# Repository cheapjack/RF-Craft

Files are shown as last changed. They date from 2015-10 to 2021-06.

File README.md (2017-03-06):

# RF-Craft




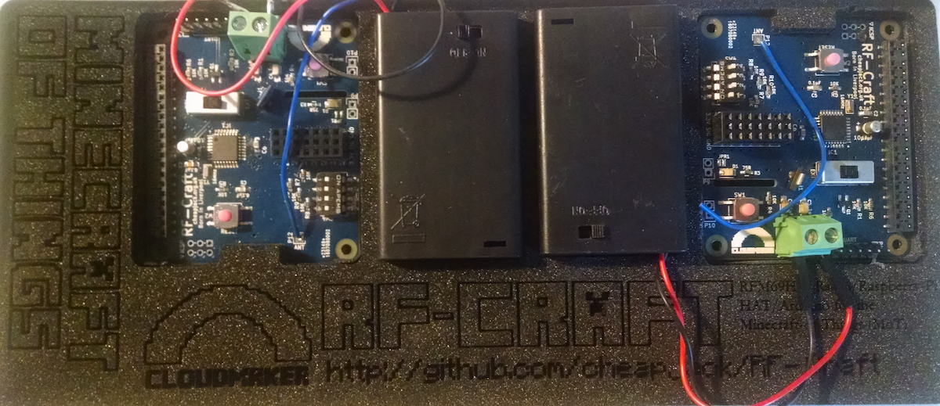
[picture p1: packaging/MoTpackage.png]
<br>
<br>

RF-Craft is a prototype Raspberry Pi [HAT](https://github.com/raspberrypi/hats) (**H**ardware **A**ttached on **T**op) arduino clone to send `mcpi` API commands wirelessly to a minecraft server. RF-Craft was built as part of Ross Dalziel's [OK Sparks Project](http://domesticscience.org.uk) and a spin-out from the [FACT](http://fact.co.uk/) [CloudMaker](http://www.fact.co.uk/projects/cloudmaker-making-minecraft-real.aspx) project research and inspired by resilient networks, the work of [Martin O'Hanlon](https://github.com/martinohanlon/mcpi) where `mcpi` is maintained via Mojang, [Shrimping.it](http://start.shrimping.it) and Minecraft modders worldwide. 

Full info from the [CloudMaker Repo](https://github.com/cheapjack/CloudMaker)

It is a board to help teach the **Internet of Things** and is inspired by the wider Minecraft community and culture where young people develop their own skillsets in order to take part in the games culture. In many ways it is the first game in mainstream consciousness where players take control of elements of the games infrastructure, independent of the original developer *Mojang*, often becoming their own **sysadmins** using custom servers for games they want to play and as a consequence, with considerable transferable skills in coding and IoT. 

Minecraft is not an open source project but the game community have, in a sense, opened up elements of it to allow extensive modding and creative hacking. This adhoc technical *culture* is what is the most valuable, not the game itself or even it's potential to educate, which is a consequence of this. After a good deal of research we've concluded that Minecraft is more representative of an independent learning culture and ecosystem on it's own and others borrowed terms and with it's own diversity. This is exciting but not necessarily always helpful to educators or learners.  

With experience, we think it should not really be confused with a universal *service* or *platform* that could be easily exploited for formal mainstream education.

Current owners, Microsoft are developing an education *platform* through [Minecraft Education](https://education.minecraft.net/). This is a very specific version of the game and so has very specific requirements to use. In this sense it *is* a platform, but like many platforms in the real world once you are on one its hard to jump to another without ladders, ropes or expensive jetpacks. We've all played on Parkour servers so we know how hard that can be!

We've tried to package up a range of resources, examples and hardware that could allow you to play with connecting versions of the game with the real world with sensors and buttons. 

Finding the right version of the game to experiment with is difficult and has it's own quite steep and confusing learning curve. We recommend keeping it simple and experimenting on a Pi. The Pi version is version 1.0 or something. It's simple and it's not changing. It's also free. There's an established community out there using the python [mcpi API](https://github.com/martinohanlon/mcpi) for it like [Martin O'Hanlon](https://github.com/martinohanlon/) and making cool stuff for it like [PatternCraft](http://patterncraft.co/).

So we've tried keeping it simple by making simple Raspeberry Pi HATS that can transmit and receive serial messages which you can parse into commands in the Raspberry Pi version of Minecraft you can make simpel HelloWorld Text Adventures, [Models of Railways](https://github.com/cheapjack/RF-Rail-Craft) or all the way up to interacting with [data](https://github.com/cheapjack/MoT), the [International Space Station](https://github.com/astro-pi/SpaceCRAFT) to punchard readers that make music just like PatternCraft.

This Open source Radio messaging system uses the [RFM69HW tranceiver chip](https://lowpowerlab.com/shop/rfm69hw)(based on the Lowpowerlab Moteino) and Frequency 868MHz to report to a central reciever to perform minecraft actions.

Its designed as a Minecraft-of-Things deluxe development board bridging the gap between Pi and Arduino without depending on both. One design parameter was to have good signal penetration through Victorian concrete and the concrete of many arts centres and/or schools for the [Ok Sparks!](http://slyrabbit.net/ok-sparks) project by [Domestic Science](http://domesticscience.org.uk). 

It was designed by artist [Ross Dalziel](http://cheapjack.org.uk) and open source engineer and technician in residence at [DoESLiverpool](http://doesliverpool.com) [Patrick Fenner AKA @DefProc](http://www.deferredprocrastination.co.uk/) and funded by [FACT](http://fact.co.uk/) and  [IT as a Utility (ITaaU) Network](http://www.itutility.ac.uk) for the [CloudMaker](http://www.fact.co.uk/projects/cloudmaker-making-minecraft-real.aspx) project following 2 years of research into the game as a social learning tool which we've since realised is, as we've said, more like a *culture*

### Features

 * On board button and LED, 
 * Digital input for a Dallas DS18B20 one-wire temperature sensor (with pullup resistor) and power rail 
 * 6 analog inputs broken out with power
 * Battery power breakout
 * Pi/External mode jumpers
 * IDE Free reciever/transmitter/Node programming switch
 * It can act as a powered HAT reciever/transmitter on board a Pi or as an independent battery powered arduino radio receiver or transmitter.
 * Open Source: Not cheap but open; but you can build them yourself!
 * Good singnal penetration through concrete castles
 * Need IoT Minecraft workshop & WiFi Down? Network Administrator at lunch? Got Pi, Got HAT Got RF-Craft - no problem!
 * Need radio arduinos for IoT prototype? Sick of Minecraft? Caps falling out of your shrimp? No problem use elsewhere!
 * Send Commands to a Receiver HAT and your Raspbians local Minecraft Pi Edition server
 * Send Commands to the Rasperry Juice Plugin on a CanaryMod server
 * Send Commands to the Rasperry Juice Plugin on `mc.fact.co.uk:25589`

### Message Format

messages are constructed of a `uint8_t` for node_id, followed by an `int8_t` for action

Possible action messages:

 * -1 : set_id
 *  0 : query_id
 *  1 : button press
 *  2 : error
 *  3 : OK

common key for messages: "changemechangeme"

all radios are in group: 87

Transmitter `node_ids` for buttons can be 1-100 but the onboard `node_id` switch can set them to 1-15 in Binary. By default with the big mode switch set to **EXT** the HAT is in transmitter mode and you need to set the `node_id` switch to 1-15. When the mode switch is set to **RPI** then the `node_id` is 254 which is a receiver. 

### Getting Started

The easiest thing to do is clone this repo into your `/home/pi` folder either with git or `wget https://github.com/cheapjack/RF-Craft/archive/master.zip` then `unzip`

You can install git with `sudo apt-get install git-core`
Then `git clone https://github.com/cheapjack/RF-Craft.git`

Then you can modify the `HelloPi.py` or `HelloSerial.py` `python 2.7` code and play with the transmitter and receiver boards pairs out of the box without even having to put the arduino sketches on. Unless you're making them yourselves from the details in the repo then well it's your box.

Then for full details you can read the nearby `GettingStarted.md` file

### RF-Craft

### Background

[The Minecraft Of Things](http://minecraftofthings.tumblr.com) sprang from research with [FACT](http://fact.co.uk/), [Dr Mark Wright](https://twitter.com/dr_mark_wright), [Adrian McEwen](http://www.mcqn.com/) and Paul Harter of [PrintCraft](http://www.printcraft.org/) funded by [IT as a Utility (ITaaU) Network](http://www.itutility.ac.uk) for the [CloudMaker](http://www.fact.co.uk/projects/cloudmaker-making-minecraft-real.aspx) project

Looking into how the Raspberry Pi could be used as an entry into embedded systems, physical computing and the Internet Of Things(IoT) we developed something that could be used in many contexts with simplicity at its core and with ideas that touched on data literacy, resilient networks and security. 

One of the big issues with use of Minecraft in education is networking often educators dont have the time or access to setup a school network for a wireless sensors to communicate with the game; we wanted to be able to be independent of this and for people to setup their own adhoc networks to follow how networks are used in real world applications.

For the final distribution of CloudMaker research we focussed on packaging up resources to help understand the Internet Of Things through Minecraft.

We took diverse approaches to reflect real IoT ecosystems; tried not to re-invent the wheel but point to fascinating education work going on in technology and post 'Maker' culture. 

We made simple arduino on a breadboard interfaces inspired by [Shrimping.It](http://start.shrimping.it) for interacting with minecraft over wired USB/FTDI adaptors, [ShrimpCraft](https://github.com/cheapjack/ShrimpCraft), a WiFi on a breadboard system [Cockle-Craft-of-Things](https://github.com/mcqn/cocklecraft-of-things) with MCQN Ltd. 

For RF-Craft we made a super robust custom PCB arduino RFM69 clone that has a more plug & python & play approach.

The receiver button pairs allow you to send wireless messages to a range of minecraft servers for augmented reality gaming and learning the Internet of Things (IoT) 

### Resources

This uses Martin O'Hanlon's [mcpi API](https://github.com/martinohanlon/mcpi) the Minecraft: Pi Edition API Python Library and his and Zhuowei's [Canary Raspberry Juice](https://github.com/martinohanlon/CanaryRaspberryJuice) plugin for use with FACT's CloudMaker Minecraft Server

### The FACT Server

The FACT CloudMaker Server is a server for prototyping multiplayer `mcpi` activity. Details for how to log on are at the [CloudMaker portal repo](https://github.com/cheapjack/CloudMaker/)

#### Plugins

 * Printbot
 * ScriptCraft
 * WorldEdit
 * Essentials

You can view the [Minecraft CloudMaker Server with this link](http://89.34.96.47:8125/)



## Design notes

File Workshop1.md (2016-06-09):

## Getting Started with RF-Craft

CloudMaker

Welcome to a teacher focussed workshop on using (and testing) RF-Craft!

### Simple setup and python Hello! sketch

We are going to cover 3 ways of using RF-Craft:

 * Sending messages to a built in Minecraft instance on board the Pi with a `receiver` HAT `Hello.py`
 * Sending messages to a local CanaryMod Server `HelloCanary.py`
 * Sending messages to the FACT Minecraft server at `mc.fact.co.uk:25565` `HelloCloudMaker.py`

They all use the same python code using the `mcpi` API 

Its well worth reading Martin O'Hanlon's [Stuff About Code API Reference](http://www.stuffaboutcode.com/p/minecraft-api-reference.html), his [Tutorial](http://www.stuffaboutcode.com/2013/04/minecraft-pi-edition-api-tutorial.html) and notes on [Connecting to other servers](http://www.stuffaboutcode.com/2014/10/minecraft-raspberryjuice-and-canarymod.html) that all the code side is based on.

### Out Of The Box

RF-Craft v1.1

Your receiver and transmitter already have receiver.ino and button.ino uploaded to them but if your in the first workshop you need to change the group ID in the Arduino code so messages from other people dont get confused with each other but we will cover that later.

Look at the 2 RF Craft boards in your pack; you will see some plastic jumpers next to the long ATMEGA328 chip: one will be connected to the `|--PI--|` side, and another connected to `|External|`. Pi is the `receiver` and External is the `button` and they have the associated code on there.

All you need to do is get the receiver HAT on your Pi header, ensure the jumpers are set to `|--PI--|`, start the PI up, get it into Desktop mode `startx`, start a minecraft game and then power up the battery pack on the button HAT, the one with jumpers set to `|External|`.

You then need to clone this repo into your home directory and use the `Hello*.py` python programmes to receive the button messages over serial and then send commands to the minecraft server of your choice.  

Do this by opening a terminal window on the Pi and going `$ cd ~` then `$ ls` to list your files
Then either use `git` or `wget https://github.com/cheapjack/RF-Craft/archive/master.zip` then `unzip master.zip`

You can install git with `sudo apt-get install git-core`
Then `git clone https://github.com/cheapjack/RF-Craft.git`

Then you can run python code like this from the terminal 

`$ python Hello.py`

To stop it press `ctrl` & `C`

Then you can edit it with a text editor or edit and run the code with the IDLE Python IDE on the Pi

We are going to run you through the basic useage today and will provide further reading to experiment with other servers

#### Hello World!

We are going to start with a HAT receiver on board the PI: You generally talk to the server with the API like this:

```
    from mcpi import minecraft
    mc = minecraft.Minecraft.create()

    mc.postToChat("Hello World!")
```

You can specify an exact server address and port in the `.create()` call like this

```
mc = minecraft.Minecraft.create("127.0.0.1")
# This is the server running on your computer, the localhost address
# or mc =minecraft.Minecraft.create("mc.fact.co.uk") 
# or mc = minecraft.Minecraft.create(server.address)
# In this case we refer to a file called server.py that specifies a server address
# Or you can just use:
# mc = minecraft.Minecraft.create()
# By default the server will be a local instance of the CanaryMod server

```

Next you need to `import serial` at the top of the programme so we can receive our HAT messages

```
#########################
# Pi/PC/Mac/Linux  mode #
# RF-Craft HAT receiver #
#########################
# use the default serial port, 'COM1', '/dev/ttyAMA0' this will change platform to platform '/dev/tty.usbserial-A400f5sm'
# You can list your serial ports in Terminal
# Open a terminal window from the menu bar
# $ ls /dev
# It should show something like this '/dev/ttyAMA0', 9600
# So therefore define your serial object like this
# Or use the serial id that shows up on the Arduino IDE
ser = serial.Serial('/dev/ttyAMA0', 9600)
#ser = serial.Serial('COM1', 9600)
#ser = serial.Serial('/dev/tty.usbserial-A400f5sm', 9600)
#ser = serial.Serial('/dev/tty.SLAB_USBtoUART', 9600)
#########################################################
# The Button sends the serial message (node , action)   #
# node is the value in #define NODEID in Line 10 of the #
# Arduino code                                          #
# in ~/RF-Craft/arduino/button/button.ino               #
# It comes with the default node of 1 on the arduino HAT#
#                                                       #
# action "1", "ButtonPressed"                           #
# action "2", "Error"                                   #
# action "3", "OK"                                      #
#                                                       #
#########################################################
```

Then we can setup our button receive message

`button1_received = "1,1\r\n"`

Finally we make a simple loop to respond to the button1_received value as serial receives it

```
while True:
    # This reads the ser object you defined before, the serial connected to the HAT
    serialcommand = str(ser.readline())
    if serialcommand == button5_received:
        print "Got mail from Button 5"
        mc.postToChat("Got mail from Button 5 saying " + serialcommand)
        mc.entity.setTilePos(4, 76,20, -64)
        sleep(1)
        mc.camera.setFollow()
```
### CanaryMod
We may not get to this in the workshop but another way of working is to run a server on a bigger computer and send messages to that.
Weve provided a server from the [CanaryMod Jenkins Repo](https://ci.visualillusionsent.net/) with a compatible plugin called Raspberry Juice and a CanaryMod server to send similar messages to a much more up to date world you can play with PC/Mac/Linux Minecraft running version `1.8`

You need to `$ cd ~/RF-Craft-master/CanaryForDistro/`
then `$ ls` to check whats there and `$ ./start.bat`
If you have JAVA installed all should be well, server will start and quit then edit the text file eula.txt  and change eula=false to eula=true and save the file. Then restart and you should be able to send messages to this server at the localhost address.

More details from Martin at his [Raspberry Juice Page](http://www.stuffaboutcode.com/2014/10/minecraft-raspberryjuice-and-canarymod.html)

CanaryMod and mcpi can't seem to agree on the coordinates of player positions and we've found you need to add -256 to x, add 64 to y and add -8 to z to make your coordinates match with the Minceraft client like this:

```
# translate mc coords on CanaryMod server for mcpi ones
# add this to x
mcx = -256
# - add this to y
mcy = 64
# - add this to z
mcz = -8
```

Likewise the FACT server can be equally confused and we ususally have to:

```
# translate mc coords on CloudMaker server for mcpi ones
# add this to x
mcx = 177
# - this from y
mcy = 64
# - this from z
mcz = 135
```

What you can also do is use your Pi as the bridge to sending messages to any minecraft server with the Raspberry Juice plugin installed like the FACT server at `mc.fact.co.uk`

You can play with all of the code in Martin O'Hanlon and David Whale's excellent book **Adventures in Minecraft** which you can get from [the Wiley publishers website](http://eu.wiley.com/WileyCDA/Section/id-823690.html) and experiment with things like [this](https://github.com/martinohanlon/minecraft-demos)

### Basic Tools

#### Multiple HATS & the Arduino IDE

If in the unlikey event you have a room full of receiver HATs then a button press message will be received by all receivers! To avoid this you can modify the arduino `button.ino` and `receiver.ino` NETWORKID value

Open the RF-Craft/arduino/button.ino sketch with your Arduino IDE

Download it [from here](https://www.arduino.cc/)

Connect the red FTDI cable adaptor to your button HAT and ensure that pins connect like this:
```
FTDI -> HAT
RST -> RST
RX -> RX
TX -> TX
VCC -> VIN
CTS -> NC #(NC stands for not Connected)
```

You can use any coloured combos of **female** to **female** jumper cable you like as long as they follow the wiring above

Now choose Tools/Board "Arduino/Genuino Uno" from the Arduino IDE menu
Choose Tools/Port "cu.usbserial-####" 
Choose Tools/Programmer "ArduinoISP"

Change line 9 from `#define NETWORKID   87` to a number of your choice:
`#define NETWORKID   88`

Now Upload your code to the HAT. As it's a button it's 3 jumpers are on the |External| side. Now you need to do the same process for your receiver HAT

Open RF-Craft/arduino/receiver/receiver.ino

Change line 9 from `#define NETWORKID   87` to a number of your choice, but the same number as your button ie::
`#define NETWORKID   88`

**REMEMBER** to move your receiver HAT jumpers to |--PI--| to |External| or the Arduino IDE cant see it. Then swap back over once you have uploaded successfully. 

#### Command Line

Behind every application on your computer is a command line where you can control it without the mouse.

 * `ls` - list where we are and what files we can look at 
 * `cd` - change directory go somewhere; we will stay here: ~/MoT/mcpi but if you get lost just type `cd ~/MoT-master`
 * `vim <file name.py>` - open a python file in vim 
 * `python HelloWorld.py` - runs the file HelloWorld.py to send a message to minecraft

#### Vim

[Vim](http://vim.rtorr.com/) (a version of Vi) is a text editor that lives pretty much on every server on the internet 

So you can edit things by typing `$ vi Hello.py` without needing the IDLE Python IDE editor.

Basically you move with the cursor keys and if you want to type something press `i` and you can type and delete as normal. When you're finished hit escape `esc` and if you want to `write` your changes type `:wq`  

 * `i` - insert text
 * `cursor keys` - move in the text
 * `esc` - stop inserting text
 * `:w` - write your changes
 * `:wq` - write your changes and quit vim

### Requirements

If you are running python code from a PC/Mac/Linux you will need to install `Python v2.7` from [here](https://www.python.org/about/gettingstarted/) and then you can follow the tutorials at [Raspberry Pi here](https://www.raspberrypi.org/learning/getting-started-with-minecraft-pi/worksheet/)

Id recommend looking at the [Hitchhiker's Guide To Python](http://docs.python-guide.org/en/latest/) for extensive tips on installing `Python 2.7` (much of what we use is transferable to `Python 3` but we stick with the Pi 2.7 for the time being) and although you can run from the command line you might want to use the Idle IDE. I'd also consider using Virtual Environments  [virtualenv](http://docs.python-guide.org/en/latest/dev/virtualenvs/).

Other useful stuff you can install are

`$ sudo apt-get install vim`
`$ sudo apt-get install screen`
`$ sudo apt-get install wicd-curse`s

### Shrimps

We've also used mcpi with the *brilliant* **Shrimped Arduino kits** from [Shrimping.it](http://shrimping.it/blog/) at its core and used prototype methods for visualising raw temperature and turbdiity data on onboard LED flashers, in Processing and in Minecraft. We used this method for the [ShrimpCraft](https://github.com/cheapjack/ShrimpCraft) project

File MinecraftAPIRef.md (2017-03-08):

# Minecraft API 

This is [Martin O'Hanlon's](https://github.com/martinohanlon) reference for the Minecraft Python API Library, which is supported on Minecraft: Pi edition and the PC/Mac/Linux version using the RaspberryJuice plugin.

If you want to know more about how to use the API, including tutorials, see his projects and download his code, visit my minecraft page.

Structure
 * minecraft.py
  * Class Minecraft - main class for connecting and interacting with the game
   * Class camera - changing camera angle and postion
   * Class player - getting and changing the players position and setting
   * Class entity - getting and changing entities position and setting
   * Class events - retreiving events which have occured in the game
 * block.py
  * Class Block - definition of a block, specifically its type
 * event.py
  *Class BlockEvent - definition of a block event, specifically what event, what block and what player
 * vec3.py
  * Class Vec3 - generic class for managing a 3 dimension vector (i.e. x,y,z)
 * connection.py - internal module used by the api
 * util.py - internal module used by the api

###Compatability
Not all functions and block types are available on all version of the api

PiEditionAvailable on Minecraft: Pi edition
Bukkit/CanaryModAvailable on RaspberryJuice

## Minecraft
"Main class for interacting with the Minecraft world, includes functions for creating a connection, modifying players and blocks and capturing events"

#### .create(address = "localhost", port = 4711)
"Create connection to Minecraft (address, port) => Minecraft object"
PiEdition
Bukkit/CanaryMod

```
#use default address and port
mc = minecraft.Minecraft.create()
#specify ip address and port
mc = minecraft.Minecraft.create("192.168.1.1", 4711)
```

#### .getBlock(x,y,z)
"Get block (x,y,z) => id:int"
PiEdition
Bukkit/CanaryMod

```
#retrieves the block type for the block at 0,0,0
blockType = mc.getBlock(0,0,0)
```

#### .getBlocks(x0,y0,z0,x1,y1,z1)
"Get a cuboid of blocks (x0,y0,z0,x1,y1,z1) => [id:int]"
Bukkit/CanaryMod

```
#get the block ids in a cuboid
blocks = mc.getBlocks(-1,-1,-1,1,1,1)
for block in blocks:
    print block
```

#### .getBlockWithData(x,y,z)
"Get block with data (x,y,z) => Block"
PiEdition
Bukkit/CanaryMod

```
#retrieves a block object for the block at 0,0,0
blockObj = mc.getBlockWithData(0,0,0)
```

#### .setBlock(x,y,z)
"Set block (x,y,z,id,[data])"
PiEdition
Bukkit/CanaryMod

```
#sets a block at an x, y, z co-ordinate to a particular type
mc.setBlock(0,0,0,block.DIRT.id)
#sets a block to a particular type and 'subtype'
mc.setblock(0,0,0,block.WOOD.id, 1)
```

#### .setBlocks(x0,y0,z0,x1,y1,z1,blockType, blockData)
"Set a cuboid of blocks (x0,y0,z0,x1,y1,z1,id,[data])"
PiEdition
Bukkit/CanaryMod

```
#sets many blocks at a time, filling the gap between 2 sets of x, y, z co-ordinates
mc.setBlocks(-1, -1, -1, 1, 1, 1, block.STONE.id)
```

#### .getHeight(x,z)
"Get the height of the world (x,z) => int"
PiEdition
Bukkit/CanaryMod

```
#find the y (vertical) of an x, z co-ordinate which represents the 'highest' (non-air) block
y = mc.getHeight(0,0)
```

#### .getPlayerEntityIds()
"Get the entity ids of the connected players => [id:int]"
PiEdition
Bukkit/CanaryMod

```
#get the entity ids of the players connected to the game
entityIds = mc.getPlayerEntityIds()
for entityId in entityIds:
    print entityId
```

#### .getPlayerEntityId(playerName)
"Get the entity id for a named player => [id:int]"
Bukkit/CanaryMod

```
#get the entity id of a name player 'martinohanlon'
entityId = mc.getPlayerEntityId("martinohanlon")
print entityId
```

#### .saveCheckpoint()
"Save a checkpoint that can be used for restoring the world"
PiEdition

```
mc.saveCheckpoint()
```

#### .restoreCheckpoint()
"Restore the world state to the checkpoint"
PiEdition

```
mc.restoreCheckpoint()
```

#### .postToChat(message)
"Post a message to the game chat"
PiEdition
Bukkit/CanaryMod

```
#write 'Hello Minecraft World' to the chat window
mc.postToChat("Hello Minecraft World")
```

#### .setting(setting, status)
"Set a world setting (setting, status). keys: world_immutable, nametags_visible"
PiEdition
Bukkit/CanaryMod

```
#change world immutable to True
mc.setting("world_immutable", True)
#change nametags_visible setting to False
mc.setting("nametags_visible", False)
```

### Minecraft.player
#### .getPos()
"Gets the player's position in the world as a Vec3 of floats (decimal numbers), if the player is in the middle of a block x.5 is returned"
PiEdition
Bukkit/CanaryMod

```
#get players position as floats
playerPos = mc.player.getPos()
```

#### .setPos(x,y,z)
"Moves the player to a position in the world by passing co-ordinates ([x,y,z])"
PiEdition
Bukkit/CanaryMod

```
#set the players position as floats
mc.player.setPos(0.0,0.0,0.0)
```

#### .getTilePos()
"Gets the position of the 'tile' the player is currently on."
PiEdition
Bukkit/CanaryMod

```
#get the position of the tile the players is on
playerTile = mc.player.getTilePos()
```

#### .setTilePos(x,y,z)
"Move the player to a tile position in the world by passing co-ordinates ([x,y,z])"

```
#set the position of the tile the player is on
mc.player.setTilePos(0,0,0)
```

#### .setting(setting, status)
"Set a player setting (setting, status). keys: autojump"

```
#change the autojump setting to True
mc.player.setting("autojump", True)
```

#### .getRotation()
"Get the rotational angle (0 to 360) for the player => [angle:float]"

```
#get the rotation of the player
angle = mc.player.getRotation()
print angle
```

#### .getPitch()
"Get the pitch angle (-90 to 90) for the player => [pitch:float]"

```
#get the pitch for the player
pitch = mc.player.getPitch()
print pitch
```

#### .getDirection()
"Get unit vector of x,y,z for the player's direction => [Vec3]"

```
#get the player's direction
direction = mc.player.getDirection()
print direction
```

### Minecraft.entity
The entity functions are used in conjunction with the .getPlayerEntityIds() function to interact with the entity (or players) in a game.  Entity functions are useful for multiplayer games.  

```
#get the entity ids of the players connected to the game
entityIds = mc.getPlayerEntityIds()
1stEntityId = entityIds[0]
2ndEntityId = entityIds[1]
```

#### .getPos(entityId)
"Gets an entities position in the world as a Vec3 of floats (decimal numbers), if the entity is in the middle of a block x.5 is returned"

```
#get first entity position as floats
entityPos = mc.entity.getPos(entityId)
```

#### .setPos(entityId,x,y,z)
"Moves the entity to a position in the world by passing co-ordinates ([x,y,z])"

```
#set the players position as floats
mc.player.setPos(entityId,0.0,0.0,0.0)
```

#### .getTilePos(entityId)
"Gets the position of the 'tile' the entity is currently on."

```
#get the position of the tile the entity is on
entityTile = mc.entity.getTilePos(entityId)
```

#### .setTilePos(entityId, x,y,z)
"Move the entity to a tile position in the world by passing co-ordinates ([x,y,z])"

```
#set the position of the tile the entity is on
mc.player.setTilePos(entityId,0,0,0)
```

#### .getRotation(entityId)
"Get the rotational angle (0 to 360) for an entity => [angle:float]"

```
#get the rotation of an entity
angle = mc.entity.getRotation(entityId)
print angle
```

#### .getPitch(entityId)
"Get the pitch angle (-90 to 90) for an entity => [pitch:float]"

```
#get the pitch for an entity
pitch = mc.entity.getPitch(entityId)
print pitch
```

#### .getDirection(entityId)
"Get unit vector of x,y,z for an entities direction => [Vec3]"

```
#get and entities direction
direction = mc.entity.getDirection(entityId)
print direction
```

### Minecraft.camera

#### .setNormal(entityId)
"Set camera mode to normal Minecraft view ([entityId])"

```
#set camera mode to normal for a specific player
mc.camera.setNormal(entityId)
```

#### .setFixed()
"Set camera mode to fixed view"

```
#set camera mode to fixed 
mc.camera.setFixed()
```

#### .setFollow(entityId)
"Set camera mode to follow an entity ([entityId])"

```
#set camera mode to follow for a specific player
mc.camera.setFollow(entityId)
```

#### .setPos(x,y,z)
"Set camera entity position (x,y,z)"

```
#set camera position to a specific position of x, y, z
mc.camera.setPos(0,0,0)
```

### Minecraft.events

#### .pollBlockHits()
"Block Hits (Only triggered by sword) => [BlockEvent]"

```
#get block event hits that have occured since the last time the function was run
blockEvents = mc.events.pollBlockHits()
for blockEvent in blockEvents:
    print blockEvent
```

#### .clearAll()
"Clear all old events"

```
#clear all events that have happened since the events where last got
mc.events.clearAll()
```

### Block
"The definition of a Block in Minecraft, used to describe a block type and (if applicable) its data; also contains constants for the blocks type id's, e.g. BLOCK.AIR.id"

```
#create block of a specific type
blockObj = block.Block(id)
#create a block of a specific type and apply a data value
blockObj = block.Block(id, data)
```

#### .id

"The id (or type) of block"

```
AIR                 = Block(0)
STONE               = Block(1)
GRASS               = Block(2)
DIRT                = Block(3)
COBBLESTONE         = Block(4)
WOOD_PLANKS         = Block(5)
SAPLING             = Block(6)
BEDROCK             = Block(7)
WATER_FLOWING       = Block(8)
WATER               = WATER_FLOWING
WATER_STATIONARY    = Block(9)
LAVA_FLOWING        = Block(10)
LAVA                = LAVA_FLOWING
LAVA_STATIONARY     = Block(11)
SAND                = Block(12)
GRAVEL              = Block(13)
GOLD_ORE            = Block(14)
IRON_ORE            = Block(15)
COAL_ORE            = Block(16)
WOOD                = Block(17)
LEAVES              = Block(18)
GLASS               = Block(20)
LAPIS_LAZULI_ORE    = Block(21)
LAPIS_LAZULI_BLOCK  = Block(22)
SANDSTONE           = Block(24)
BED                 = Block(26)
COBWEB              = Block(30)
GRASS_TALL          = Block(31)
WOOL                = Block(35)
FLOWER_YELLOW       = Block(37)
FLOWER_CYAN         = Block(38)
MUSHROOM_BROWN      = Block(39)
MUSHROOM_RED        = Block(40)
GOLD_BLOCK          = Block(41)
IRON_BLOCK          = Block(42)
STONE_SLAB_DOUBLE   = Block(43)
STONE_SLAB          = Block(44)
BRICK_BLOCK         = Block(45)
TNT                 = Block(46)
BOOKSHELF           = Block(47)
MOSS_STONE          = Block(48)
OBSIDIAN            = Block(49)
TORCH               = Block(50)
FIRE                = Block(51)
STAIRS_WOOD         = Block(53)
CHEST               = Block(54)
DIAMOND_ORE         = Block(56)
DIAMOND_BLOCK       = Block(57)
CRAFTING_TABLE      = Block(58)
FARMLAND            = Block(60)
FURNACE_INACTIVE    = Block(61)
FURNACE_ACTIVE      = Block(62)
DOOR_WOOD           = Block(64)
LADDER              = Block(65)
STAIRS_COBBLESTONE  = Block(67)
DOOR_IRON           = Block(71)
REDSTONE_ORE        = Block(73)
SNOW                = Block(78)
ICE                 = Block(79)
SNOW_BLOCK          = Block(80)
CACTUS              = Block(81)
CLAY                = Block(82)
SUGAR_CANE          = Block(83)
FENCE               = Block(85)
GLOWSTONE_BLOCK     = Block(89)
BEDROCK_INVISIBLE   = Block(95)
STONE_BRICK         = Block(98)
GLASS_PANE          = Block(102)
MELON               = Block(103)
FENCE_GATE          = Block(107)
GLOWING_OBSIDIAN    = Block(246)
NETHER_REACTOR_CORE = Block(247)
```

#### .data
"The data (or sub-type) of a block"

Data Values of blocks:
```
WOOL:
0: White
1: Orange
2: Magenta
3: Light Blue
4: Yellow
5: Lime
6: Pink
7: Grey
8: Light grey
9: Cyan
10: Purple
11: Blue
12: Brown
13: Green
14: Red
15:Black

WOOD:
0: Oak (up/down)
1: Spruce (up/down)
2: Birch (up/down)
(below not on Pi)
3: Jungle (up/down)
4: Oak (east/west)
5: Spruce (east/west)
6: Birch (east/west)
7: Jungle (east/west)
8: Oak (north/south)
9: Spruce (north/south)
10: Birch (north/south)
11: Jungle (north/south)
12: Oak (only bark)
13: Spruce (only bark)
14: Birch (only bark)
15: Jungle (only bark)

WOOD_PLANKS (Not on Pi):
0: Oak
1: Spruce
2: Birch
3: Jungle

SAPLING:
0: Oak
1: Spruce
2: Birch
3: Jungle (Not on Pi)

GRASS_TALL:
0: Shrub
1: Grass
2: Fern
3: Grass (color affected by biome) (Not on Pi)

TORCH:
1: Pointing east
2: Pointing west
3: Pointing south
4: Pointing north
5: Facing up

STONE_BRICK:
0: Stone brick
1: Mossy stone brick
2: Cracked stone brick
3: Chiseled stone brick

STONE_SLAB / STONE_SLAB_DOUBLE:
0: Stone
1: Sandstone
2: Wooden
3: Cobblestone
4: Brick
5: Stone Brick
Below - not on Pi
6: Nether Brick
7: Quartz

Not on Pi
SNOW_BLOCK:
0-7: Height of snow, 0 being the lowest, 7 being the highest.

TNT:
0: Inactive
1: Ready to explode

LEAVES:
1: Oak leaves
2: Spruce leaves
3: Birch leaves

SANDSTONE:
0: Sandstone
1: Chiseled sandstone
2: Smooth sandstone

STAIRS_[COBBLESTONE, WOOD]:
0: Ascending east
1: Ascending west
2: Ascending south
3: Ascending north
4: Ascending east (upside down)
5: Ascending west (upside down)
6: Ascending south (upside down)
7: Ascending north (upside down)

LADDERS, CHESTS, FURNACES, FENCE_GATE:
2: Facing north
3: Facing south
4: Facing west
5: Facing east

[WATER, LAVA]_STATIONARY:
0-7: Level of the water, 0 being the highest, 7 the lowest

NETHER_REACTOR_CORE:
0: Unused
1: Active
2: Stopped / used up
```

### BlockEvent
"The definition of a BlockEvent in Minecraft, used to describe an event in Minecraft affecting blocks; returned by the Minecraft.events.pollBlockHits() method."
```
blockEvent = mc.events.pollBlockHits()
```
#### .type
"Type of block event; there is only 1 event currently implemented BlockEvent.HIT"

blockEventType = blockEvent.type

BlockEvent types:
0: BlockEvent.HIT

#### .pos
"The position of the block where the event occured, i.e. the block which was hit.  .pos returns a Vec3 object of x,y,z co-ordinates"

blockEventPos = BlockEvent.pos

#### .face
"The face of the block where the event occured"

blockEventFace = BlockEvent.face

#### .entityId
"entityId of the player who caused the block event, i.e. the player who hit the block"

blockEventPlayer - BlockEvent.entityId
Vec3
"The definition of a 3 part vector in Minecraft, i.e. a set of x, y, z co-ordinates; x and z are the horizontal positions, y the vertical"

#### position = vec3.Vec(0,0,0)

.x
"x position"

xPos = position.x
.y
"y position"

yPos = position.y
.z
"z position"

zPos = position.z

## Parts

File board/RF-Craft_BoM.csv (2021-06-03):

Qty | Line Item | Manufacturer | MPN | Octopart URL | Schematic Reference | Internal Part Number | Description | Total Qty (@ Batch Size: 1) | SKU | SKU | Packaging | Packaging | Unit Price (@ Batch Size: 1) | Unit Price (@ Batch Size: 1) | In Stock | In Stock | MOQ | MOQ | URL | URL | Distributor [null] | SKU [null] | Packaging [null] | Unit Price (@ Batch Size: 1) [null] | Line Total [null] | Batch Total [null] | In Stock [null] | MOQ [null] | URL [null] | Notes
 |  |  |  |  |  |  |  |  | Farnell | RS Components | Farnell | RS Components | Farnell | RS Components | Farnell | RS Components | Farnell | RS Components | Farnell | RS Components
1 | UWX1C100MCL1GB | Nichicon | UWX1C100MCL1GB | https://octopart.com/uwx1c100mcl1gb-nichicon-203107 | C1 |  | 10µF electrolytic capacitor | 1 | 8823022RL | 7395548 | Cut Tape |  |  |  | 2771 | 5845 | 5 | 10 | https://octopart-clicks.com/click/track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 | https://octopart-clicks.com/click/track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 | MCM Electronics | 31-8210 |  | 0.06591190000000001 | 0.06591190000000001 | 0.06591190000000001 | 39 |  | https://octopart-clicks.com/click/track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
3 | MC0805B104K500CT | Multicomp | MC0805B104K500CT | https://octopart.com/mc0805b104k500ct-multicomp-10529614 | C2, C5, C6 |  | 0.1µF 0805 Capacitor | 3 | 1759265RL |  | Cut Tape |  |  |  | 217450 |  | 10 |  | https://octopart-clicks.com/click/track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 |  | Newark | 06R3742 | Cut Tape | 0.067889257 | 0.203667771 | 0.203667771 | 11315 | 1 | https://octopart-clicks.com/click/track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
2 | MC1206B105K500CT | Multicomp | MC1206B105K500CT | https://octopart.com/mc1206b105k500ct-multicomp-10529438 | C3, C4 |  | 1µF 1206 Capacitor | 2 | 1759454RL |  | Cut Tape |  |  |  | 37488 |  | 5 |  | https://octopart-clicks.com/click/track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 |  | Newark | 06R4217 | Cut Tape | 0.252442577 | 0.504885154 | 0.504885154 | 3346 | 1 | https://octopart-clicks.com/click/track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
2 | MC0603N220K500CT | Multicomp | MC0603N220K500CT | https://octopart.com/mc0603n220k500ct-multicomp-10530022 | C7, C8 |  | 22pF 0603 Capacitor | 2 | 2309012RL |  | Cut Tape |  | 0.0046 |  | 30154 |  | 1 |  | https://octopart-clicks.com/click/track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 |  | element14 APAC | 2309012 | Cut Tape | 0.002774385136358088 | 0.005548770272716176 | 0.005548770272716176 | 74311 | 1 | https://octopart-clicks.com/click/track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
1 | SML-LX1206SRW-TR | Lumex | SML-LX1206SRW-TR | https://octopart.com/sml-lx1206srw-tr-lumex-550942 | D1 |  | Red 1206 LED | 1 | 2062242 |  |  |  | 0.0614 |  | 3173 |  | 1 |  | https://octopart-clicks.com/click/track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 |  | Farnell | 2062242 |  | 0.0614 | 0.0614 | 0.0614 | 3173 | 1 | https://octopart-clicks.com/click/track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
1 | TC1108-3.3VDBTR | Microchip | TC1108-3.3VDBTR | https://octopart.com/tc1108-3.3vdbtr-microchip-540426 | I1 |  | 3.3V low dropout, linear regulator | 1 | 1557422RL | 8234309 | Cut Tape |  | 0.388 |  | 1105 | 2600 | 1 | 20 | https://octopart-clicks.com/click/track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 | https://octopart-clicks.com/click/track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 | Avnet Express | TC1108-3.3VDBTR/BKN |  | 0.2418307611 | 0.2418307611 | 0.2418307611 | 43 | 1 | https://octopart-clicks.com/click/track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
1 | ATMEGA328P-PU | Atmel | ATMEGA328P-PU | https://octopart.com/atmega328p-pu-atmel-42866773 | IC1 |  | Push fit into socket | 1 | 1715487 | 6962260 |  |  | 2.35 | 2.39 | 8801 | 4969 | 1 | 1 | https://octopart-clicks.com/click/track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 | https://octopart-clicks.com/click/track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 | Seeed Studio | 310010051 |  | 1.977357 | 1.977357 | 1.977357 | 30000 | 1 | https://octopart-clicks.com/click/track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
1 | 1-2199298-9 | TE Connectivity | 1-2199298-9 | https://octopart.com/1-2199298-9-te+connectivity-39188588 | IC1 |  | DIP-28 Socket (solder to board) | 1 | 2445626 |  |  |  |  |  | 1234 |  | 10 |  | https://octopart-clicks.com/click/track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 |  | Onlinecomponents.com | 121992989 | Bulk | 0.268261433 | 0.268261433 | 0.268261433 | 1861 | 1 | https://octopart-clicks.com/click/track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
1 | RFM69HW-868S2 | RF Solutions | RFM69HW-868S2 | https://octopart.com/rfm69hw-868s2-rf+solutions-52732388 | IC2 |  | 868MHz High output, packet radio module | 1 |  |  |  |  |  |  |  |  |  |  |  |  | Digi-Key | RFM69HW-868S2-ND | Bag | 6.81529046 | 6.81529046 | 6.81529046 | 8 | 1 | https://octopart-clicks.com/click/track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
4 | REF-182665-03 |  |  |  | J1 |  | 40-pin surface mount, through hole header socket | 4
1 | M20-9992046 | Harwin | M20-9992046 | https://octopart.com/m20-9992046-harwin-2627752 | P1, P3, P4 |  | 1 part split over 3 positions | 1 | 1022262 | 6813007 |  |  |  |  | 1916 | 110 | 10 | 10 | https://octopart-clicks.com/click/track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 | https://octopart-clicks.com/click/track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 | Mouser | M20-9992046 |  | 0.40206259 | 0.40206259 | 0.40206259 | 889 |  | https://octopart-clicks.com/click/track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
1 | BSS138 | Fairchild Semiconductor | BSS138 | https://octopart.com/bss138-fairchild+semiconductor-13127972 | Q1 |  | N-channel MOSFET | 1 | 9845330 | 6710324 |  |  |  |  | 121317 | 13860 | 5 | 10 | https://octopart-clicks.com/click/track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 | https://octopart-clicks.com/click/track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 | Freelance Electronics | BSS138 |  | 0.00659119 | 0.00659119 | 0.00659119 | 11239 |  | https://octopart-clicks.com/click/track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
4 | MCWR08X1002FTL | Multicomp | MCWR08X1002FTL | https://octopart.com/mcwr08x1002ftl-multicomp-50550529 | R1, R2, R4, R5 |  | 10Kohm 0805 resistor | 4 | 2447553 |  | Cut Tape |  |  |  | 104420 |  | 10 |  | https://octopart-clicks.com/click/track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 |  | Farnell | 2447553 | Cut Tape |  |  |  | 104420 | 10 | https://octopart-clicks.com/click/track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
1 | CRGH0603J75R | TE Connectivity | CRGH0603J75R | https://octopart.com/crgh0603j75r-te+connectivity-24382109 | R3 |  | 75ohm 0603 resistor | 1 | 2331711 | 8075605 | Cut Tape |  |  | 0.47 | 3700 | 94 | 10 | 1 | https://octopart-clicks.com/click/track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 | https://octopart-clicks.com/click/track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 | RS Components | 8075605 |  | 0.47 | 0.47 | 0.47 | 94 | 1 | https://octopart-clicks.com/click/track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
1 | KSEK43GLFS | C&K Components | KSEK43G LFS | https://octopart.com/ksek43g+lfs-c%26k+components-33963906 | SW1 |  | Tactile pushbutton switch | 1 | 2435308 |  |  |  | 0.12 |  | 731 |  | 1 |  | https://octopart-clicks.com/click/track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 |  | Farnell | 2435308 |  | 0.12 | 0.12 | 0.12 | 731 | 1 | https://octopart-clicks.com/click/track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
1 | MCRSD16000F183000RR | Multicomp | MCRSD16000F183000RR | https://octopart.com/mcrsd16000f183000rr-multicomp-10528717 | Y1 |  | 16MHz crystal resonator | 1 | 2395958 |  |  |  | 0.169 |  | 4300 |  | 1 |  | https://octopart-clicks.com/click/track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 |  | element14 APAC | 2395958 |  | 0.1484296047951577 | 0.1484296047951577 | 0.1484296047951577 | 8591 | 1 | https://octopart-clicks.com/click/track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

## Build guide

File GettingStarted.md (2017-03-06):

## Getting Started with RF-Craft
#### AA Battery Pack - RF-Craft Button - Pi & Hat/Computer & UART - Serial - Command Line - Minecraft -  Simples!



**RF-Craft** is a *simple* messaging system to send serial messages by low power radio to a Raspberry Pi when attached as a HAT or any serial connection that uses a UART adaptor. Refer to Setup-RPi-Hat.md for setup instructions.

It comes in a receiver and transmitter pair. RF-Craft is essentially an experiment in designing physical IoT devices with young people to communicate with  Minecraft. Most of the learning here is about participatory ecosystems in the design process both for users and developers. 

But we wanted RF-Craft to let you do anything with these messages. So no Apps, complicated bluetooth pairing or custom software just open-source simplicity and `serial` communication the most basic and so univerally useful communication protocol. In our case we are using python-serial to parse `serial` messages into commands to `mcpi` a python API for the Raspberry Pi version of Minecraft because there is currently a community of young people and educators doing that. But equally they could move a robot, make a cup of tea or send a tweet

### Hardware

#### Out Of The Box

 * Your **receiver** is the **RF-Craft HAT** without battery flashed with the sketch `receiver.ino` 
 * Your **transmitter** is the **RF-Craft HAT** with a battery pack flashed with the sketch `button.ino` 

If you are within range of other transmitters you may want to change the `NETWORK_ID` and the `ENCRYPTKEY` in the Arduino code on both so messages from other people dont get confused with each other but we will cover that later. You will need a UART interface attached to the P1 UART jumpers next to the external power input [available here](http://start.shrimping.it/kit/cp2102.html)

You can still switch each HAT between transmitter & receiver mode when you are ignoring RaspberryPi and you want to use as an arduino radio. 

Look at the 2 RF Craft boards in your pack; you will see a sliding switch next to the tiny square ##ATMEGA328P## chip: set it to the **RPI** side and the board is a **receiver** ready to send the received serial commands through the HAT pins to a Raspberry Pi or over a UART interface (not included but [available here](http://start.shrimping.it/kit/cp2102.html)

**EXT** Pi is the **button** mode and lets you set an ID number with the set of 4 switches marked ON APEMS 1234. Set these switches off and on in binary to get `NODE_ID` numbers 1-15. 

 * So to get `NODE_ID 1` set switch 1 to *on* and 2-4 to *off* 
 * So to get `NODE_ID 2` set switch 2 to *on* and 1,3 & 4 to *off* 
 * To get `NODE_ID 3` set switch 1 & 2 to *on* and 3 & 4 to *off* and so on. 

Now you can use the button to send a message to your receiver.

## Software

### Simple setup and python Hello! sketches

RF-Craft works can work in a few ways 

 * Sending messages to a running Minecraft instance on board the Pi with a `receiver` HAT `Hello.py`
 * Sending messages to a local CanaryMod Server `HelloCanary.py`
 * Sending messages to the FACT Minecraft server at `mc.fact.co.uk:25589` `HelloCloudMaker.py`
 * Sending messages to each other, arduino to arduino and interacting with Serial on another computer using a UART serial adaptor for arduino
 * Sending & receiving serial messages with python to trigger text and other things. Check out Adventures-in-RFCraft.md

All minecraft options use the same python code using the `mcpi` API but we advise you stick with your Pi. Put it on the same wifi network and other RPi players could join and watch whats going on like we did for [RF-Rail-Craft](http://github.com/cheapjack/RF-Rail-Craft) for **Museum of Science & Industry Manchester** for the **Lever Prize** which [Cloudmaker](https://github.com/cheapjack/CloudMaker/) won kickstarting the **FACTLab** project Dr Mark Wright put together.

Its well worth reading Martin O'Hanlon's [Stuff About Code API Reference](http://www.stuffaboutcode.com/p/minecraft-api-reference.html), his [Tutorial](http://www.stuffaboutcode.com/2013/04/minecraft-pi-edition-api-tutorial.html). His work is the original inspiration for this project.

And if you want to interact with non-Pi servers read his notes on [Connecting to other servers](http://www.stuffaboutcode.com/2014/10/minecraft-raspberryjuice-and-canarymod.html) that all the code side is based on.

First get on the internet & clone this repo into your home directory and use the `Hello*.py` python programmes to receive the button messages over serial and then send commands to the minecraft server of your choice.  

Do this by opening a terminal window on the Pi and going `$ cd ~` then `$ ls` to list your files
Then either use `git` or `wget https://github.com/cheapjack/RF-Craft/archive/master.zip` then `unzip master.zip`

You can install git with `sudo apt-get install git-core`
Then `git clone https://github.com/cheapjack/RF-Craft.git` what's good about this is that you can get any future updates from this server with a simple `git pull`. Go [here for a git 101](https://rogerdudler.github.io/git-guide/) it's a useful thing to know and it really sets you up for open sourcing your work in the future. You can read about what Im interested in about git [here](https://gitlab.com/redock/critical-kits/blob/master/Why_Git.md)

Then you can run python code like this from the terminal 

`pi$ python HelloSerial.py`

To stop it press `ctrl` & `C`

Then you can edit it with a text editor like [vim](http://vim.rtorr.com/) Install **vim** with `pi$ sudo apt-get install vim` or edit and run the code with the built-in RPi IDLE Python IDE on the Pi.

### Testing

Before thinking about Minecraft lets check we are receiving serial.

Check you've got serial installed:
`sudo apt-get install python-serial`

Verify it all works by using screen
Install it first if you dont have it; its handy!
`sudo apt-get install screen`

then with your HAT connected in RPI mode or UART connected no another device listen on the `/dev/ttyS0` serial port at 9600 baudrate that your HAT communicates with. This port varies system to system.

`screen /dev/ttyS0 9600`

Power your other **RF-Craft HAT** in **EXT** mode and set a **NODE** value of 1 using the 1234 switch (next to the analoginput block on the board), and you should receive the message `1,1` which means `NODEID=1,Button Pressed`

**TIP** To set a node ID of 1 Just set the node switch 1 to ON which is 1 in binary
or for a node ID of 3 set the node switch 1 and 2 to ON, 3 in binary.

Now try `HelloSerial.py` on your Pi with `python HelloSerial.py`

#### Hello World!

Follow the guide at [Setup-RPi-Hat.md](Setup-RPi-Hat.md) in the Repo and run HelloSerial.py

`pi$ python HelloSerial.py` press your powered transmitter onboard button, watch the led flash morse code and you should receive the message "Got mail from Button 1"

#### Hello Minecraft World!

We are going to start with a HAT receiver on board the PI: You generally talk to the server with the API like this:

```
    from mcpi import minecraft
    mc = minecraft.Minecraft.create()

    mc.postToChat("Hello World!")
```

You can specify an exact server address and port in the `.create()` call like this

```
mc = minecraft.Minecraft.create("127.0.0.1")
# This is the server running on your computer, the localhost address
# or mc =minecraft.Minecraft.create("mc.fact.co.uk") 
# In this case we refer to a file called server.py that specifies a server address
# Or you can just use:
# mc = minecraft.Minecraft.create()

```
Remember to have Minecraft running on the Pi before running HelloPi.py
Next you need to `import serial` at the top of the programme so we can receive our HAT messages

```
#########################
# Pi/PC/Mac/Linux  mode #
# RF-Craft HAT receiver #
#########################
# use the default serial port, 'COM1', '/dev/ttyAMA0' this will change platform to platform '/dev/tty.usbserial-A400f5sm'
# Please refer to Setup-RPi-Hat.md for help setting up serial ports on the pi.
# On windows the ports are usually COM1, COM2 etc but you will need to look into that. We are focussing on the Pi
# On UNIX sysems/Pi or Linux you can list your serial ports in Terminal
# Open a terminal window from the menu bar
# $ ls /dev/tty*
# It should show up a list with one port something like this '/dev/ttyAMA0', 9600
# So therefore define your serial object like this
ser = serial.Serial('/dev/ttyS0', 9600)
#ser = serial.Serial('/dev/ttyAMA0', 9600)
#ser = serial.Serial('COM1', 9600)
#ser = serial.Serial('/dev/tty.usbserial-A400f5sm', 9600)
#ser = serial.Serial('/dev/tty.SLAB_USBtoUART', 9600)
#########################################################
# The Button sends the serial message (node , action)   #
# node is the value in #define NODEID in Line 10 of the #
# Arduino code which you can change with the 1-4 NODE_ID#
# switches                                              #
# in ~/RF-Craft/arduino/button/button.ino               #
# It comes with the default node of 1 on the arduino HAT#
#                                                       #
# action "1", "ButtonPressed"                           #
# action "2", "Error"                                   #
# action "3", "OK"                                      #
#                                                       #
#########################################################
```

Then we can setup our button receive variable to listen for a button press

`button1_received = "1,1\r\n"`

Finally we make a simple loop to respond to the button1_received value as serial receives it

```
while True:
    # This reads the ser object you defined before, the serial connected to the HAT
    serialcommand = str(ser.readline())
    if serialcommand == button1_received:
        print "Got mail from Button 1"
        mc.postToChat("Got mail from Button 1 saying " + serialcommand)
        mc.entity.setTilePos(4, 76,20, -64)
        sleep(1)
        mc.camera.setFollow()
```

### CanaryMod
We may not get to this in the workshop but another way of working is to run a server on a bigger computer and send messages to that.
Weve provided a server from the [CanaryMod Jenkins Repo](https://ci.visualillusionsent.net/) with a compatible plugin called Raspberry Juice and a CanaryMod server to send similar messages to a much more up to date world you can play with PC/Mac/Linux Minecraft running version `1.8`

You need to `$ cd ~/RF-Craft-master/CanaryForDistro/`
then `$ ls` to check whats there and `$ ./start.bat`
If you have JAVA installed all should be well, server will start and quit then edit the text file eula.txt  and change eula=false to eula=true and save the file. Then restart and you should be able to send messages to this server at the localhost address.

More details from Martin at his [Raspberry Juice Page](http://www.stuffaboutcode.com/2014/10/minecraft-raspberryjuice-and-canarymod.html)

CanaryMod and mcpi can't seem to agree on the coordinates of player positions and we've found you need to add -256 to x, add 64 to y and add -8 to z to make your coordinates match with the Minceraft client like this:

```
# translate mc coords on CanaryMod server for mcpi ones
# add this to x
mcx = -256
# - add this to y
mcy = 64
# - add this to z
mcz = -8
```

Likewise the FACT server can be equally confused and we ususally have to:

```
# translate mc coords on CloudMaker server for mcpi ones
# add this to x
mcx = 177
# - this from y
mcy = 64
# - this from z
mcz = 135
```

What you can also do is use your Pi as the bridge to sending messages to any minecraft server with the Raspberry Juice plugin installed like the FACT server at `mc.fact.co.uk`

You can play with all of the code in Martin O'Hanlon and David Whale's excellent book **Adventures in Minecraft** which you can get from [the Wiley publishers website](http://eu.wiley.com/WileyCDA/Section/id-823690.html) and experiment with things like [this](https://github.com/martinohanlon/minecraft-demos)

### Basic Tools

#### Multiple HATS & the Arduino IDE

If in the unlikey event you have a room full of receiver HATs then a button press message will be received by all receivers! To avoid this you can modify the arduino `button.ino` and `receiver.ino` NETWORKID value

Open the RF-Craft/arduino/button.ino sketch with your Arduino IDE

Download it [from here](https://www.arduino.cc/)

Connect the red FTDI cable adaptor to your button HAT and ensure that pins connect like this:
```
FTDI -> HAT
RST -> RST
RX -> RX
TX -> TX
VCC -> VIN
CTS -> NC #(NC stands for not Connected)
```

You can use any coloured combos of **female** to **female** jumper cable you like as long as they follow the wiring above

Now choose Tools/Board "Arduino/Genuino Uno" from the Arduino IDE menu
Choose Tools/Port "cu.usbserial-####" 
Choose Tools/Programmer "ArduinoISP"

Change line 9 from `#define NETWORKID   87` to a number of your choice:
`#define NETWORKID   88`

Now Upload your code to the HAT. As it's a button it's 3 jumpers are on the |External| side. Now you need to do the same process for your receiver HAT

Open RF-Craft/arduino/receiver/receiver.ino

Change line 9 from `#define NETWORKID   87` to a number of your choice, but the same number as your button ie::
`#define NETWORKID   88`

**REMEMBER** to move your receiver HAT jumpers to |--PI--| to |External| or the Arduino IDE cant see it. Then swap back over once you have uploaded successfully. 

#### Command Line

Behind every application on your computer is a command line where you can control it without the mouse.

 * `ls` - list where we are and what files we can look at 
 * `cd` - change directory go somewhere; we will stay here: ~/MoT/mcpi but if you get lost just type `cd ~/MoT-master`
 * `vim <file name.py>` - open a python file in vim 
 * `python HelloWorld.py` - runs the file HelloWorld.py to send a message to minecraft

#### Vim

[Vim](http://vim.rtorr.com/) (a version of Vi) is a text editor that lives pretty much on every server on the internet 

So you can edit things by typing `$ vi Hello.py` without needing the IDLE Python IDE editor.

Basically you move with the cursor keys and if you want to type something press `i` and you can type and delete as normal. When you're finished hit escape `esc` and if you want to `write` your changes type `:wq`  

 * `i` - insert text
 * `cursor keys` - move in the text
 * `esc` - stop inserting text
 * `:w` - write your changes
 * `:wq` - write your changes and quit vim

### Requirements

If you are running python code from a PC/Mac/Linux you will need to install `Python v2.7` from [here](https://www.python.org/about/gettingstarted/) and then you can follow the tutorials at [Raspberry Pi here](https://www.raspberrypi.org/learning/getting-started-with-minecraft-pi/worksheet/)

Id recommend looking at the [Hitchhiker's Guide To Python](http://docs.python-guide.org/en/latest/) for extensive tips on installing `Python 2.7` (much of what we use is transferable to `Python 3` but we stick with the Pi 2.7 for the time being) and although you can run from the command line you might want to use the Idle IDE. I'd also consider using Virtual Environments  [virtualenv](http://docs.python-guide.org/en/latest/dev/virtualenvs/).

Other useful stuff you can install are

`$ sudo apt-get install vim`
`$ sudo apt-get install screen`
`$ sudo apt-get install wicd-curse`s

### Shrimps

We've also used mcpi with the *brilliant* **Shrimped Arduino kits** from [Shrimping.it](http://shrimping.it/blog/) at its core and used prototype methods for visualising raw temperature and turbdiity data on onboard LED flashers, in Processing and in Minecraft. We used this method for the [ShrimpCraft](https://github.com/cheapjack/ShrimpCraft) project

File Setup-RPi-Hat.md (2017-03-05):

# Setup RPi for use with HATS

You need to disable serial console on your Pi and enable UART with 
`sudo raspi-config`

Select Advanced Options/Serial and disable the serial login shell or Interface Options/Serial and disable the serial login shell but enable the hardware(UART)

Then you need to `sudo reboot`

If you are *still* not receiving messages on your **receiver HAT** in **RPI mode** from your **RF-Craft HAT** in **EXT** transmitter mode with a NODE_ID of 1 ie (1,1), you may also have to follow the below [instructions](https://www.hackster.io/fvdbosch/uart-for-serial-console-or-hat-on-raspberry-pi-3-5be0c2) from [Frederick Vandenbosch](https://www.hackster.io/fvdbosch)

## Raspberry Pi 3 & Raspbian Jessie 2017

It seems the recently launched Raspberry Pi 3 behaves differently with regards to the UART interface on the GPIO header. In this guide I go through the steps I took to get the UART working for serial console or HAT communication.

I am assuming you are using a recent Raspbian Jessie image (2016-03-18 or more recent) on Raspberry Pi 3, that the file system has been expanded and that enough space is left for the software updates to be installed.

Let’s go!

### Update Software

Make sure you are on the internet. If in doubt `ping google.com` and if you are receiving 64 bytes on each ping you're ok. `ctrl-c` to stop the pings (they stop themselves after 10). Be aware depending on speed of your internet this can take a while ;)

The first thing you’ll probably need to do is to ensure all software components are up-to-date. Update the repository and upgrade the installed packages:

`pi@raspberrypi:~ $ sudo apt-get update && sudo apt-get upgrade -y`

Update the firmware:

`pi@raspberrypi:~ $ sudo rpi-update`

Reboot to apply the changes:

`pi@raspberrypi:~ $ sudo reboot`

### Enable UART

 A new property has been introduced to enable the UART on the Pi. This property will put the core frequency to a minimum, ensuring stability. It’s possible to put the core frequency to maximum as well, assuming the power supply is powerful enough and the Pi 3 is properly cooled (heatsink!).

 Enabling UART with minimum core frequency:

 `pi@raspberrypi:~ $ sudo nano /boot/config.txt`

The file can be found on the SD card and accessed that way or when the Pi is booted and running

```
# Enable UART
enable_uart=1
```

More information on this newly introduced property can be [found here](https://www.raspberrypi.org/forums/viewtopic.php?f=28&t=141195)

### Disable Console

To disable the console, edit the following file as follows:

 `pi@raspberrypi:~ $ sudo nano /boot/cmdline.txt`

As before the file can be found on the SD card and accessed that way on any computer or when the Pi is booted and running

```
#dwc_otg.lpm_enable=0 console=serial0,115200 console=tty1 root=/dev/mmcblk0p2 rootfstype=ext4 elevator=deadline fsck.repair=yes rootwait
dwc_otg.lpm_enable=0 console=tty1 root=/dev/mmcblk0p2 rootfstype=ext4 elevator=deadline fsck.repair=yes rootwait
```

Reboot to apply the change:

`pi@raspberrypi:~ $ sudo reboot`

### Testing

Before thinking about Minecraft lets check we are receiving serial.

Check you've got serial installed:
`sudo apt-get install python-serial`

Verify it all works by using screen
Install it first if you dont have it; its handy!
`sudo apt-get install screen`

then listen on the `/dev/ttyS0` serial port at 9600 baudrate that your HAT communicates with.

`screen /dev/ttyS0 9600`

Power your other **RF-Craft HAT** in **EXT** mode and set a **NODE** value of 1 using the 1234 switch (next to the analoginput block on the board), and you should receive the message `1,1` which means `NODEID=1,Button Pressed`

**TIP** To set a node ID of 1 Just set the node switch 1 to ON which is 1 in binary
or for a node ID of 3 set the node switch 1 and 2 to ON, 3 in binary.

Now try `HelloSerial.py` on your Pi with `python HelloSerial.py`

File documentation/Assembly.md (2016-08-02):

# Building your own

You can contact [@cheapjack](https://twitter.com/cheapjack) and buy a complete board or you can download this repo, get your PCB's made with someone like [Dirty PCBS](http://dirtypcbs.com/) and assemble your own.

You *could* try to solder complonents onto the board by hand but if you're making more than one it could take a long time. Instead get access to a DIY reflow oven with an [Arduino Re-Flow Oven controller shield](http://www.rocketscream.com/blog/docs-item/reflow-controller-shield/) with [code](https://github.com/rocketscream/Reflow-Oven-Controller), a laser cutter some HF 212 Solder Paste, Mylar Sheet and use a DIY pick and place machine and assemble your PCB components on board.  
Felix Rusu from [Low Power Labs](http://lowpowerlab.com/moteino/#misc) has some great tutorials on this [here](https://www.youtube.com/watch?v=YhavXauuWqY).

# KiCad

## Gerber to Laser Solder Mask

**Assumes use of KiCad or similar schematic editor**

Open Gerber for `F.Mask.gbr` in gerber view
 * `Print` and select:
  * Accurate scale
  * Print to file (pdf)

Open pdf in InkScape
 * Convert to outlines and centre on the right
 * Colour for engraving (green)

Export `.dxf` (and `.eps`)

Engrave Mylar sheet
 * Engrave at Speed 250 / Power 25 (0.1) (bi-dir on)

## Reflow oven

Refer to the [DoES Liverpool](https://github.com/DoESLiverpool) [Reflow Oven Page](https://github.com/DoESLiverpool/wiki/wiki/Reflow-Oven)
i
Select the RoHS-DP - Lead free solder profile

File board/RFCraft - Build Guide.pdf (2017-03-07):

SMD

References | Unit Qty | IPN | Description | Placed
SHIELD 1 | 1 | PCBRFcraftR3 | RFCraft-Rev3
R1, R2, R4, R5, R6, R7, R8, R9, R10, R12 | 10 | R6X103 | 10Kohm 0603 resistor
R3 | 1 | R6X750 | 75ohm 0603 resistor
R11 | 1 | R6X472 | 4.7K 0603 Resistor
C2, C5, C6 | 3 | C8X104 | 0.1µF 0805 Capacitor
C3, C4 | 2 | C12U105 | 1µF 1206 Capacitor
D1 | 1 | L12R | Red 1206 LED
Y1 | 1 | YS16 | 16MHz crystal resonator
Q1 | 1 | MN138 | N-channel MOSFET
I1 | 1 | VS333 | 3.3V low dropout, linear regulator
C1 | 1 | CE3X106 | 10µF electrolytic capacitor 3mm SMD
SW1, SW2 | 2 | BS06 | Tactile pushbutton switch
IC1 | 1 | IC328A | ATmega328
SW4 | 1 | SWD4 | 4way DIP switch array
J1 | 0 | ISS40 | Raspberry Pi 2x20 pin thu-header SMD

Then flash the Arduino bootloader via ICSP port

Thru-hole
References | Unit Qty | IPN | Description | Placed
P2–P8 | 1 | HDT3X7 | 7×3 socket strip
SW3 | 1 | SW4PDT | 4PDT switch
P1 | 1 | | FTDI header
P11 | 1 | TB52 | 2way screw terminal
IC2 | 1 | RFM69HW | 868MHz High output, packet radio module

Non-soldered
References | Unit Qty | IPN | Description | Placed
J1 (optional) | 1 | IS40 | 2x20 raspberry pi stacking header

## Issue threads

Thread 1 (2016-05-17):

Setup the Workshop at FACT

cheapjack, 2016-05-17:
- [x] Confirm numbers - 5
- [x] Get back to FACT re Workshop Times
- [x] Setup Times
- [x] Ask For Equipment ie Pi's
- [x] Radames help
- [x] Mark attendance
- [ ] Laura attendance
- [ ] Have Ribbon Cable?
- [x] Have FTDI/USB?
  - [x] Using Cockle-craft FTDI's
- [x] Have Pi's?
- [x] Have Mac's ?
- [ ] Have Drivers?
- [ ] Have Temperature sensors?
- [ ] Have a FACT Cockle?
- [ ] Have Python?
- [ ] Change profiles to 1.7.10
- [ ] Have Buttons?
- [ ] Have Receivers?
- [ ] Have custom disk images?
- [ ] Prepped repo?
- [ ] Have Passwords & checked?
- [ ] Have RF-Craft sign?
- [ ] OK Sparks! Documentation

Closed 2016-11-10.

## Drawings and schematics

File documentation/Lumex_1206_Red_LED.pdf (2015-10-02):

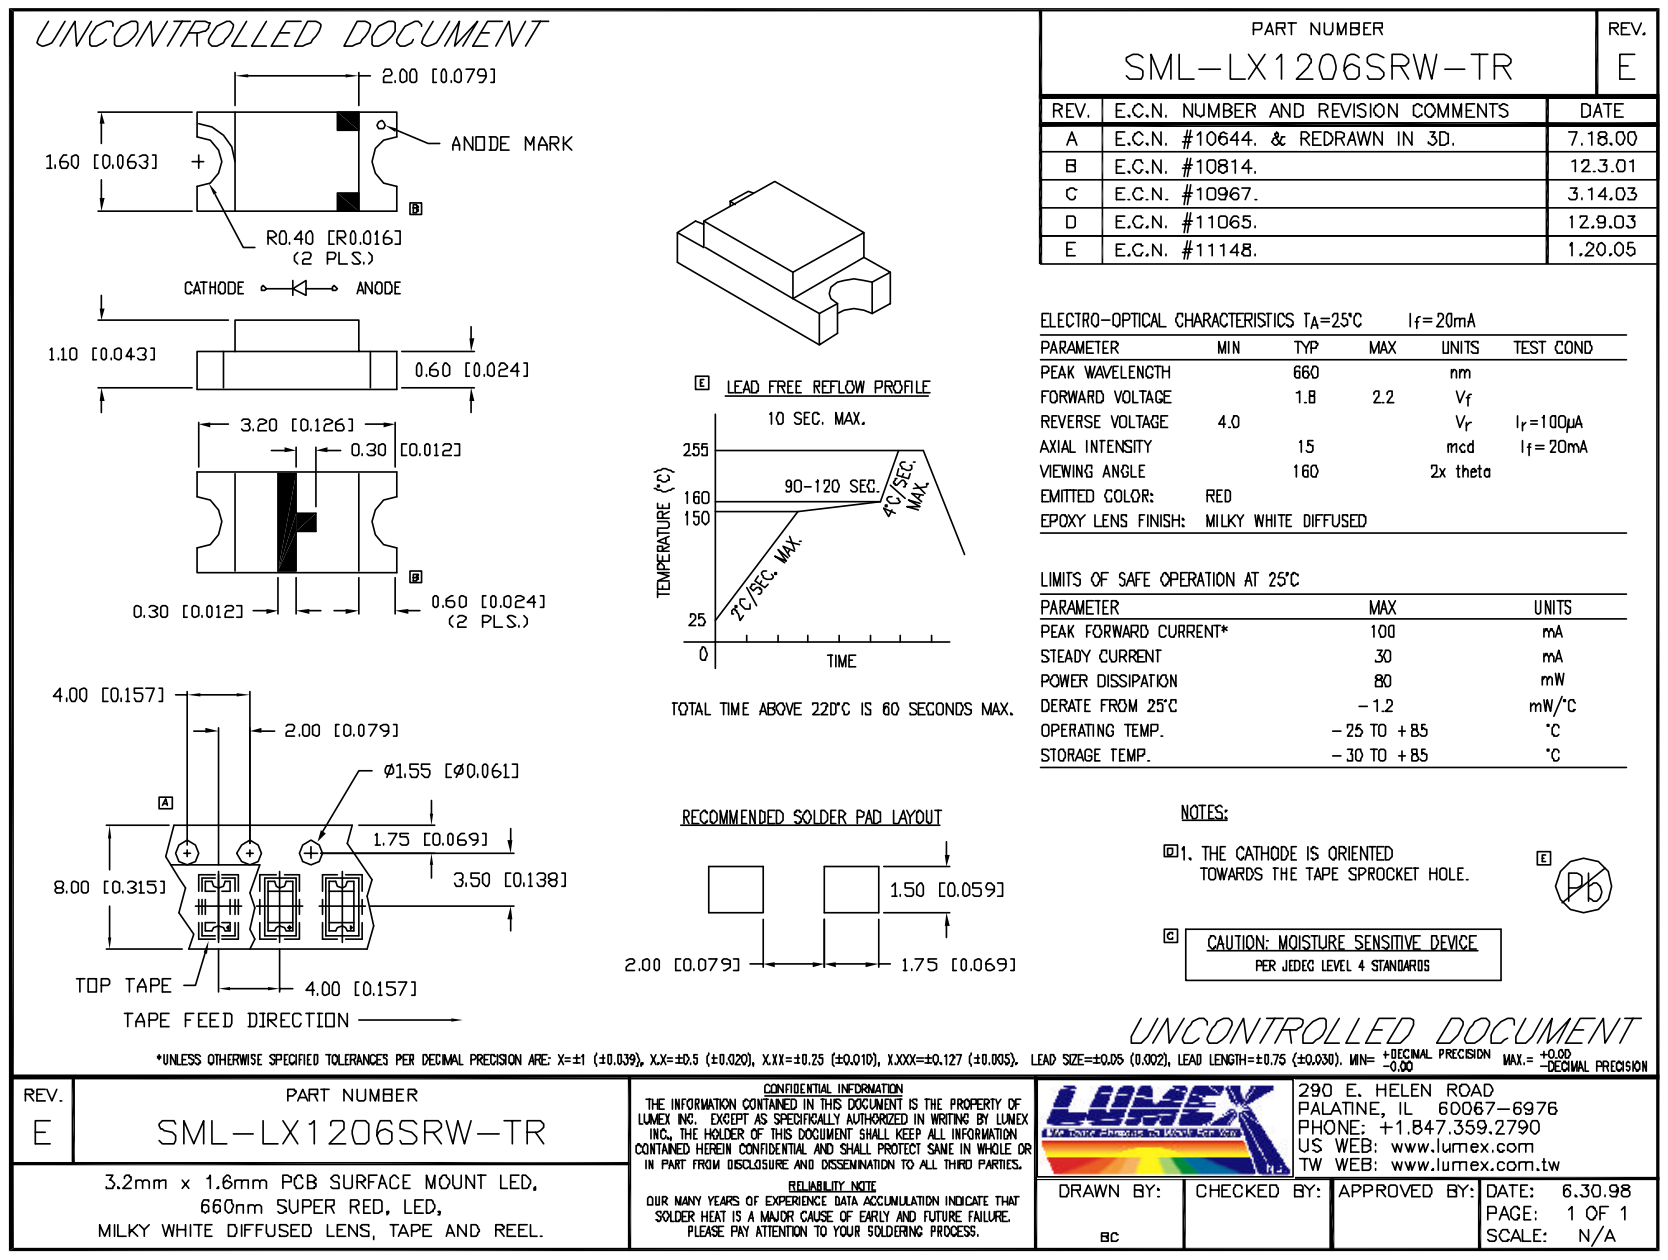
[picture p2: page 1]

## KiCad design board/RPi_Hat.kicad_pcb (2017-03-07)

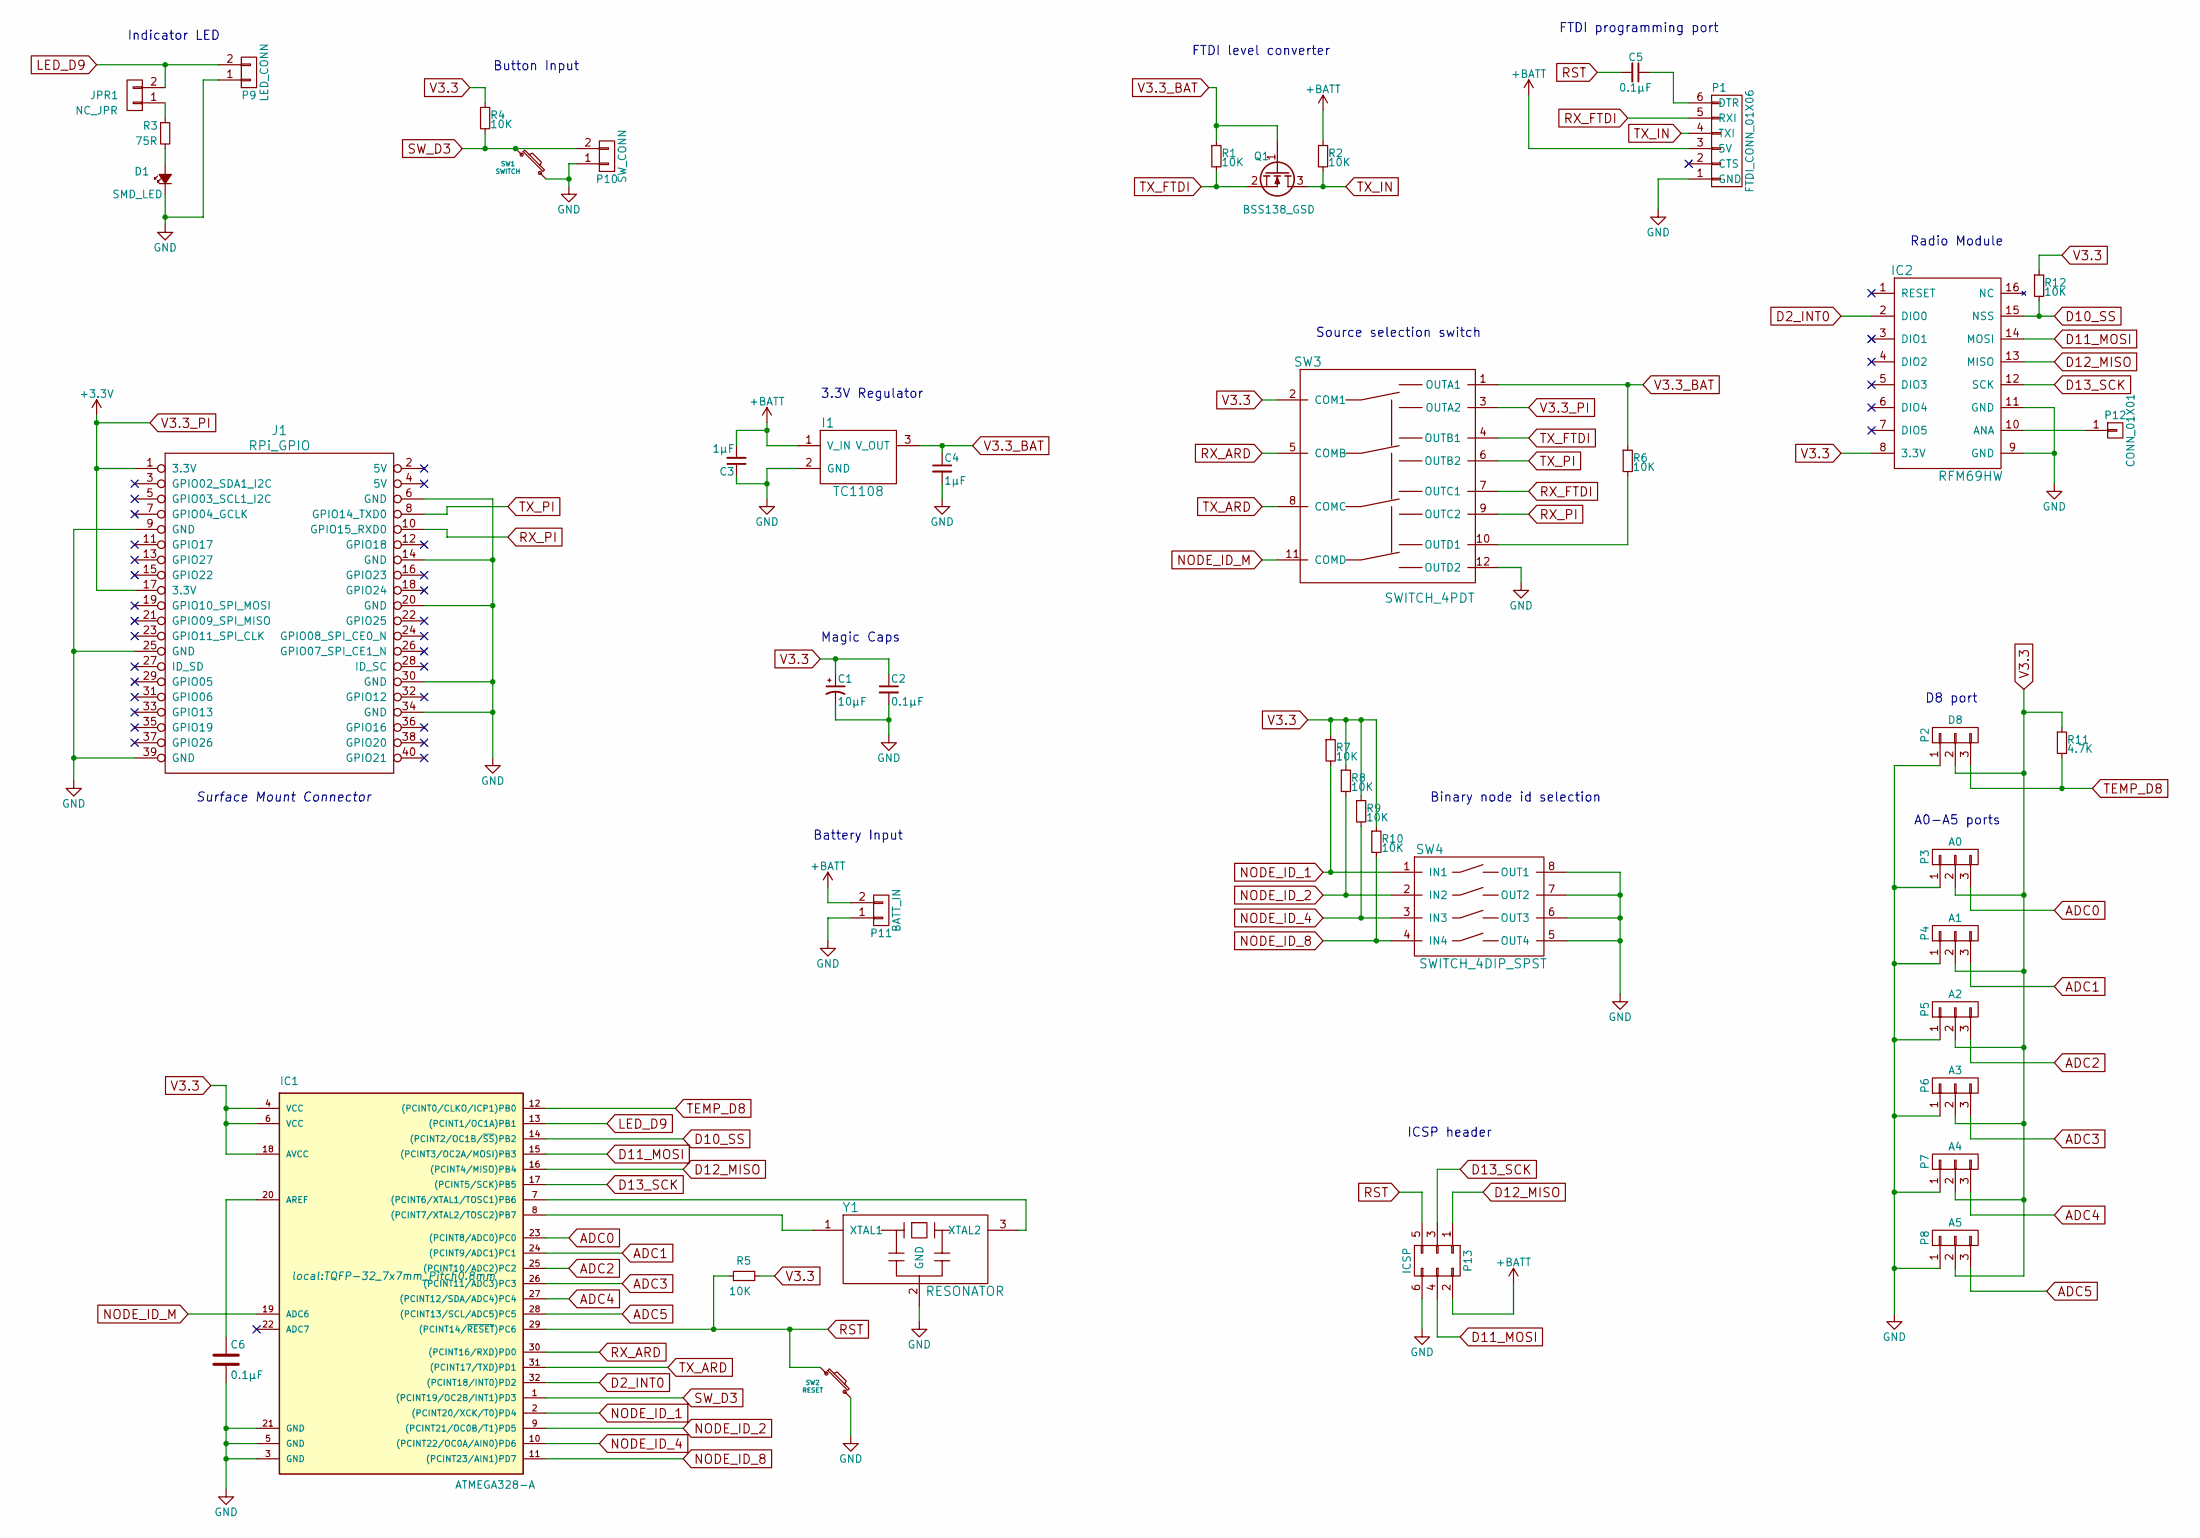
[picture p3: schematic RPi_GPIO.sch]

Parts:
C1: 10µF; c_elec_3x5.3
C2, C5, C6: 0.1µF; C_0805_HandSoldering
C3, C4: 1µF; C_1206_HandSoldering
D1: SMD_LED; LED_1206
I1: TC1108; SOT-223
IC1: ATMEGA328-A; TQFP-32_7x7mm_Pitch0.8mm
IC2: RFM69HW; RFM69
J1: RPi_GPIO; Samtec_HLE-120-02-XXX-DV-BE-XX-XX
JPR1: NC_JPR; NC_SMD_JPR
P1: FTDI_CONN_01X06; Pin_Header_Straight_1x06
P2: D8; Pin_Header_Straight_1x03
P3: A0; Pin_Header_Straight_1x03
P4: A1; Pin_Header_Straight_1x03
P5: A2; Pin_Header_Straight_1x03
P6: A3; Pin_Header_Straight_1x03
P7: A4; Pin_Header_Straight_1x03
P8: A5; Pin_Header_Straight_1x03
P9: LED_CONN; Pin_Header_Straight_1x02
P10: SW_CONN; Pin_Header_Straight_1x02
P11: BATT_IN; bornier2
P12: CONN_01X01; Pin_Header_Straight_1x01
P13: ICSP; ISCP_header
Q1: BSS138_GSD; SOT-23_Handsoldering
R1, R2, R4, R5, R6, R7, R8, R9, R10, R12: 10K; R_0603_HandSoldering
R3: 75R; R_0603_HandSoldering
R11: 4.7K; R_0603_HandSoldering
SW1: SWITCH; KSEx00G_SW
SW2: RESET; KSEx00G_SW
SW3: SWITCH_4PDT; SWITCH_4PDT_MFS401N
SW4: SWITCH_4DIP_SPST; SW_DIP_04_GULL_BINARY
Y1: RESONATOR; Resonator_3.2x1.3

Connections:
+BATT: C3.2, I1.1 (V_IN), P1.3 (5V), P11.2, P13.2, R2.1
ADC0: IC1.23 ((PCINT8/ADC0)PC0), P3.3
ADC1: IC1.24 ((PCINT9/ADC1)PC1), P4.3
ADC2: IC1.25 ((PCINT10/ADC2)PC2), P5.3
ADC3: IC1.26 ((PCINT11/ADC3)PC3), P6.3
ADC4: IC1.27 ((PCINT12/SDA/ADC4)PC4), P7.3
ADC5: IC1.28 ((PCINT13/SCL/ADC5)PC5), P8.3
D2_INT0: IC1.32 ((PCINT18/INT0)PD2), IC2.2 (DIO0)
D10_SS: IC1.14 ((PCINT2/OC1B/~SS~)PB2), IC2.15 (NSS), R12.2
D11_MOSI: IC1.15 ((PCINT3/OC2A/MOSI)PB3), IC2.14 (MOSI), P13.4
D12_MISO: IC1.16 ((PCINT4/MISO)PB4), IC2.13 (MISO), P13.1
D13_SCK: IC1.17 ((PCINT5/SCK)PB5), IC2.12 (SCK), P13.3
GND: C1.2, C2.2, C3.1, C4.2, C6.2, D1.1 (K), I1.2 (GND), IC1.3 (GND), IC1.5 (GND), IC1.21 (GND), IC2.9 (GND), IC2.11 (GND), J1.6 (GND), J1.9 (GND), J1.14 (GND), J1.20 (GND), J1.25 (GND), J1.30 (GND), J1.34 (GND), J1.39 (GND), P1.1 (GND), P2.1, P3.1, P4.1, P5.1, P6.1, P7.1, P8.1, P9.1, P10.1, P11.1, P13.6, SW1.2, SW2.2, SW3.12 (OUTD2), SW4.5 (OUT4), SW4.6 (OUT3), SW4.7 (OUT2), SW4.8 (OUT1), Y1.2 (GND)
LED_D9: IC1.13 ((PCINT1/OC1A)PB1), JPR1.2, P9.2
NODE_ID_1: IC1.2 ((PCINT20/XCK/T0)PD4), R7.2, SW4.1 (IN1)
NODE_ID_2: IC1.9 ((PCINT21/OC0B/T1)PD5), R8.2, SW4.2 (IN2)
NODE_ID_4: IC1.10 ((PCINT22/OC0A/AIN0)PD6), R9.2, SW4.3 (IN3)
NODE_ID_8: IC1.11 ((PCINT23/AIN1)PD7), R10.2, SW4.4 (IN4)
NODE_ID_M: IC1.19 (ADC6), SW3.11 (COMD)
unnamed: C5.1, P1.6 (DTR)
unnamed: C6.1, IC1.20 (AREF)
unnamed: D1.2 (A), R3.2
unnamed: IC1.7 ((PCINT6/XTAL1/TOSC1)PB6), Y1.3 (XTAL2)
unnamed: IC1.8 ((PCINT7/XTAL2/TOSC2)PB7), Y1.1 (XTAL1)
unnamed: IC2.10 (ANA), P12.1
unnamed: JPR1.1, R3.1
unnamed: R6.2, SW3.10 (OUTD1)
RST: C5.2, IC1.29 ((PCINT14/~RESET~)PC6), P13.5, R5.1, SW2.1
RX_ARD: IC1.30 ((PCINT16/RXD)PD0), SW3.5 (COMB)
RX_FTDI: P1.5 (RXI), SW3.7 (OUTC1)
RX_PI: J1.10 (GPIO15_RXD0), SW3.9 (OUTC2)
SW_D3: IC1.1 ((PCINT19/OC2B/INT1)PD3), P10.2, R4.2, SW1.1
TEMP_D8: IC1.12 ((PCINT0/CLKO/ICP1)PB0), P2.3, R11.2
TX_ARD: IC1.31 ((PCINT17/TXD)PD1), SW3.8 (COMC)
TX_FTDI: Q1.2 (S), R1.2, SW3.4 (OUTB1)
TX_IN: P1.4 (TXI), Q1.3 (D), R2.2
TX_PI: J1.8 (GPIO14_TXD0), SW3.6 (OUTB2)
V3.3: C1.1, C2.1, IC1.4 (VCC), IC1.6 (VCC), IC1.18 (AVCC), IC2.8 (3.3V), P2.2, P3.2, P4.2, P5.2, P6.2, P7.2, P8.2, R4.1, R5.2, R7.1, R8.1, R9.1, R10.1, R11.1, R12.1, SW3.2 (COM1)
V3.3_BAT: C4.1, I1.3 (V_OUT), Q1.1 (G), R1.1, R6.1, SW3.1 (OUTA1)
V3.3_PI: J1.1 (3.3V), J1.17 (3.3V), SW3.3 (OUTA2)

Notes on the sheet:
Surface Mount Connector
Battery Input
FTDI programming port
FTDI level converter
Source selection switch
3.3V Regulator
Magic Caps
Indicator LED
Button Input
Radio Module
A0-A5 ports
Binary node id selection
D8 port
ICSP header

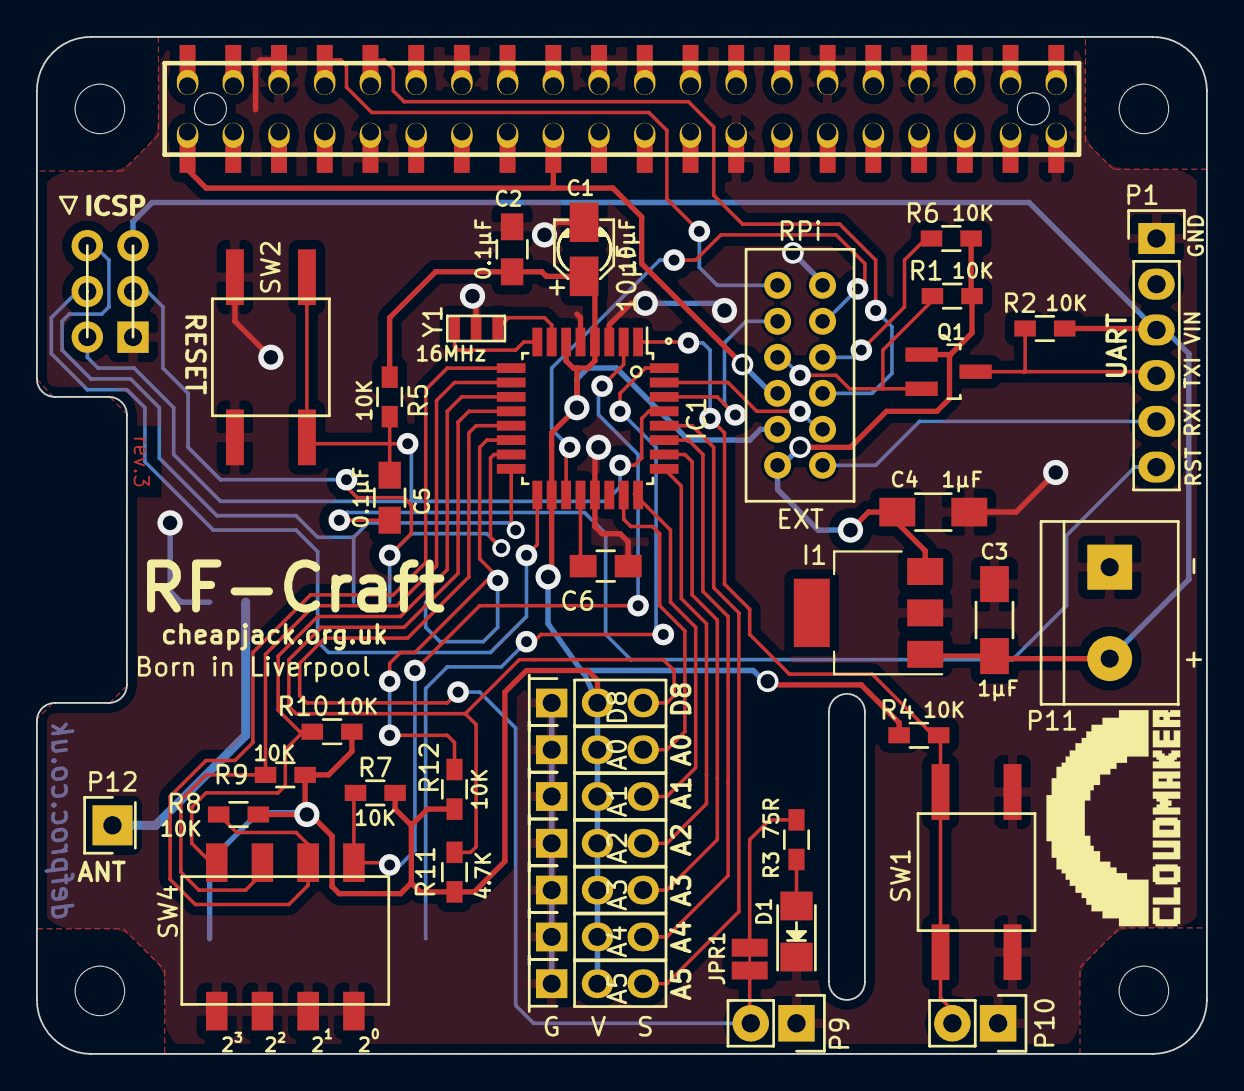
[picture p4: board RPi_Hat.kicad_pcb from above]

Board: 2 copper layers, 65.0 x 56.5 mm, 43 parts (1 on the bottom side), 40 nets.

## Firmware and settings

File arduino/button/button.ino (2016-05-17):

#include <RFM69.h>
#include <EEPROM.h>
#include <avr/power.h>
#include <avr/sleep.h>

#define SERIAL_PRINT         1 //choose serial reporting on (1) or off (0)
#define SERIAL_BAUD       9600

#define NETWORKID           87
#define NODEID               1 // 1-100 for nodes
#define NODEID_LOCATION     78
#define GATEWAYID          254
#define FREQUENCY  RF69_868MHZ
#define IS_RFM69HW
#define REQUESTACK        true // whether to request ACKs for sent messages
#define ACK_TIME            50 // # of ms to wait for an ack
#define LISTEN_FOR_REPLY  true // choose if we want to listen and parse a reply
#define WAIT_FOR_REPLY 10000UL // how long should we wait for a reply before going back to sleep?

byte this_node_id = NODEID;

#define LED                  9
#define BUTTON            INT1 // choose an interrupt pin

#define DBOUNCE_TMOUT    500UL
#define LED_TIMEOUT    12000UL
#define SLEEP_TIMEOUT   1000UL

#define DOT              200UL
#define DASH             600UL // DOT*3

#define QUERY_ID             0
#define SET_ID              -1
#define BUTTON_PRESS         1
#define ERROR                2
#define OK                   3
#define ACK                  4
#define NAK                  5
#define NON                  6
#define NO_DATA              7

#define ENCRYPTKEY "changemechangeme"

typedef struct {
  uint8_t action;
  uint8_t node;
} Payload;
Payload myPacket;
Payload yourPacket;

RFM69 radio;

unsigned long lastSend = 0;
unsigned long lastButton = 0;
unsigned long lastAction = 0;
volatile boolean button = false;
volatile boolean radioCalled = true;

byte isButton(byte k_node_id = this_node_id)
{
  if (k_node_id >= 1 && k_node_id <= 100) {
    return true;
  } else {
    return false;
  }
}

byte isGateway(byte k_node_id = this_node_id)
{
  if (k_node_id == 254) {
    return true;
  } else {
    return false;
  }
}

void setup()
{
  // set up ports for minimal leakage current
  DDRD &= B00000011;       // set Arduino pins 2 to 7 as inputs, leaves 0 & 1 (RX & TX) as is
  DDRB = B00000000;        // set pins 8 to 13 as inputs
  PORTD |= B11111100;      // enable pullups on pins 2 to 7
  PORTB |= B11111111;      // enable pullups on pins 8 to 13
#if SERIAL_PRINT == 1
  Serial.begin(SERIAL_BAUD);
#endif
  pinMode(LED, OUTPUT);
  digitalWrite(LED, LOW);
  pinMode(BUTTON, INPUT);
  digitalWrite(9, LOW);

  radio.initialize(FREQUENCY, NODEID, NETWORKID);
#ifdef IS_RFM69HW
  radio.setHighPower();
#endif
  radio.encrypt(ENCRYPTKEY);
  radio.sleep(); //sleep right away to save power

  byte node;
  EEPROM.get(NODEID_LOCATION, node);
  if (isButton(node) || isGateway(node)) {
    this_node_id = node;
  } else {
    this_node_id = NODEID;
  }
  myPacket.node = this_node_id;
  myPacket.action = 0;

  attachInterrupt(BUTTON, buttonCheck, FALLING);
#if SERIAL_PRINT == 1
  Serial.println("Ready...");
#endif
}

void loop()
{
  while (Serial.available() > 0) {
    char character = Serial.peek();
    int code = Serial.parseInt();

    if (character == 'h') {
      Serial.println(F("Accepted input"));
      Serial.println(F("(action),(node_id)"));
      Serial.println(F("where action can be: "));
      Serial.println(F("-1, set_id"));
      Serial.println(F(" 0, query_id"));
      Serial.println(F(" 1, button press"));
      Serial.println(F(" 2, error"));
      Serial.println(F(" 3, OK"));
      Serial.println(F("and node_id can be: "));
      Serial.println(F(" 1-100 for buttons"));
      Serial.println(F(" 254 for the gateway"));
    } else if (code == QUERY_ID) {
      Serial.print(F("NODEID: "));
      Serial.println(this_node_id);
    } else if (code == SET_ID) {
      int node = Serial.parseInt();
      if (isButton(node) || isGateway(node)) {
        this_node_id = node;
        EEPROM.put(NODEID_LOCATION, this_node_id);
        radio.initialize(FREQUENCY, this_node_id, NETWORKID);
      }
      Serial.print(F("NODEID: "));
      Serial.println(this_node_id);
    } else if (code == BUTTON_PRESS) {
      if (isGateway()) {
        Serial.println(F("NOT_A_BUTTON"));
      } else {
        button = true;
      }
    } else if (code == ERROR || code == OK) {
      int node = Serial.parseInt();
      if (isButton(node)) {
        myPacket.action = code;
        myPacket.node = node;
        radio.send(myPacket.node, (const void*)(&myPacket), sizeof(myPacket), REQUESTACK);
        if (waitForAck()) {
          Serial.println(F("ACK"));
        } else {
          Serial.println(F("NAK"));
        }
      } else {
        Serial.print(F("NON"));
        Serial.println(node);
      }
    } else {
      Serial.print(F("ERROR: "));
      Serial.println(code);
    }
    Serial.find('\n');
  }

  if (isButton()) {
    //on button press,
    if (radioCalled == false) {
      lastAction = millis();
      //make a radio call
      myPacket.action = BUTTON_PRESS;
      detachInterrupt(BUTTON);
#if SERIAL_PRINT == 1
      Serial.print("Calling... ");
      Serial.print(myPacket.node);
      Serial.print(":");
      Serial.print(myPacket.action);
#endif
      radio.send(GATEWAYID, (const void*)(&myPacket), sizeof(myPacket), REQUESTACK);
      radioCalled = true;
      boolean listen_for_reply = LISTEN_FOR_REPLY;
      if (REQUESTACK) {
#if SERIAL_PRINT == 1
        Serial.print(" - waiting for ACK...");
#endif
        if (waitForAck()) {
#if SERIAL_PRINT == 1
          Serial.print("ok!");
#endif
          // pulse the onboard led
          morseLed(ACK);
          lastAction = millis();
          //pulseLed(LED_TIMEOUT);
          digitalWrite(LED, LOW);
          //button = false;
        } else {
#if SERIAL_PRINT == 1
          Serial.print("no reply...");
#endif
          button = false;
          lastAction = millis();
          morseLed(NAK);
          listen_for_reply = false;
        }
        if (listen_for_reply == true) {
          unsigned long reply_time = millis();
          boolean replied = false;
          while (millis() - reply_time <= WAIT_FOR_REPLY) {
            //digitalWrite(LED, HIGH);
            if (radio.receiveDone()) {
              //digitalWrite(LED, LOW);
              if (radio.DATALEN != sizeof(yourPacket)) {
#if SERIAL_PRINT == 1
                Serial.print("Invalid payload recieved");
#endif
                morseLed(NON);
              } else {
                replied = true;
                yourPacket = *(Payload*)radio.DATA;
#if SERIAL_PRINT == 1
                Serial.print("Recieved: ");
                Serial.print(yourPacket.node);
                Serial.print(":");
                Serial.print(yourPacket.action);
                Serial.println();
#endif
              }
              if (radio.ACKRequested()) {
                radio.sendACK();
#if SERIAL_PRINT == 1
                Serial.println("ACK sent");
#endif
              }
              break;
            }
          }
          if (replied == true) {
            if (yourPacket.action == OK) {
              Serial.print("received OK");
              morseLed(OK);
              gap();
              pulseLed(LED_TIMEOUT);
            } else {
              Serial.print("received: ");
              Serial.print(yourPacket.action);
              morseLed(yourPacket.action);
            }
          } else {
#if SERIAL_PRINT == 1
            Serial.print("no message: ");
#endif
            morseLed(NO_DATA);
          }
          digitalWrite(LED, LOW);
        }
      }
      button = false;
      radio.sleep();
      attachInterrupt(BUTTON, buttonCheck, FALLING);
#if SERIAL_PRINT == 1
      Serial.println();
#endif
    lastAction = millis();
    }

    // reduce battery consumption with sleep mode
    //if (millis() - lastAction >= SLEEP_TIMEOUT) {
//#if SERIAL_PRINT == 1
      //Serial.print("Sleeping...zzz...");
      //delay(100);
//#endif
      //set_sleep_mode(SLEEP_MODE_STANDBY);
      //sleep_enable();
      //sleep_mode();
      //sleep_disable();
//#if SERIAL_PRINT == 1
      //Serial.println(" Awake!");
//#endif
      //lastAction = millis();
    //}
  }// end of isButton
}

static bool waitForAck()
{
  unsigned long now = millis();
  while (millis() - now <= ACK_TIME)
    if (radio.ACKReceived(GATEWAYID))
      return true;
  return false;
}

void buttonCheck()
{
  // interrupt function for button
  // check for debounce timeout
  if (millis() - lastButton >= DBOUNCE_TMOUT) {
    lastButton = millis();
    button = !button;
    radioCalled = false;
  }
}

void pulseLed(unsigned long time)
{
  unsigned long startTime = millis();
  while (millis() - startTime <= (unsigned long)time && button == true) {
      float val = (exp(sin((millis()-startTime)/1000.0*PI)) - 0.36787944)*108.0;
      analogWrite(LED, val);
  }
}

void morseLed(byte k_message)
{
  if (k_message == ERROR) {
    // E
    dot();
    gap();
    // R
    dot(); dash(); dot();
    gap();
    // R
    dot(); dash(); dot();
  } else if (k_message == OK) {
    // O
    dash(); dash(); dash();
    gap();
    // K
    dash(); dash(); dash();
  } else if (k_message == ACK) {
    // A
    dot(); dash();
    gap();
    // C
    dash(); dot(); dash(); dot();
    gap();
    // K
    dash(); dot(); dash();
  } else if (k_message == NAK) {
    // N
    dash(); dot();
    gap();
    // A
    dot(); dash();
    gap();
    // K
    dash(); dot(); dash();
  } else if (k_message == NON) {
    // N
    dash(); dot();
    // A
    dot(); dash();
    // N
    dash(); dot();
  } else if (k_message == NO_DATA) {
    // N
    dash(); dot();
    // O
    dash(); dash(); dash();
    // D
    dash(); dot(); dot();
    // A
    dot(); dash();
    // T
    dash();
    // A
    dot(); dash();
  } else {
    // ?
    dot(); dot(); dash(); dash(); dot(); dot();
  }
}

void dot()
{
  digitalWrite(LED, HIGH);
  delay(DOT);
  digitalWrite(LED, LOW);
  delay(DOT);
}

void dash()
{
  digitalWrite(LED, HIGH);
  delay(DASH);
  digitalWrite(LED, LOW);
  delay(DOT);
}

void gap()
{
  // space is normally 3*DOT, but each dot/dash ends in
  // a single dot length delay.
  delay(DOT*2);
}

void space()
{
  delay(DOT*6);
}

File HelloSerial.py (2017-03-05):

#!/bin/python

import serial

# if using with RPi 2 or earlier with pre 2016 Raspbian Jessie
# disable serial console with sudo apt-get raspi-config
# & refer to Setup-RPi-Hat.md and use ttyAMA0 like so
# ser = serial.Serial('/dev/ttyAMA0', 9600)
# if using a UART serial adaptor on Unix/Mac
# ser = serial.Serial('/dev/tty.SLAB_USBtoUART', 9600)
#if using RPi 3 with Raspbian Jessie 2016 and onwards releases follow instructions to disable serial and enable UART from instructions in Setup-RPi-Hat.md
ser = serial.Serial('/dev/ttyS0', 9600)


# assign your button id strings
button1_received = "1,1\r\n"
button2_received = "2,1\r\n"
button3_received = "3,1\r\n"
button4_received = "4,1\r\n"
button5_received = "5,1\r\n"


while True:
    serialcommand = str(ser.readline())
    if serialcommand == button1_received:
        print "Got mail from Button 1"
        sleep(1)
    # add other elif statements for the other button states

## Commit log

2015-08-05 first working versions of the button and receiver codes
2015-10-01 gitignore for ano and kicad
2015-10-01 first draft of HAT shape board and schematic
    [RPi_GPIO.sch, RPi_Hat.kicad_pcb, RPi_Hat.sch]
2015-10-02 first draft of the HAT layout
    [RPi_GPIO.sch, RPi_Hat.kicad_pcb]
2015-10-02 resonator and led datasheets
2015-10-05 changed arduino-IDE friendly files to hard links
2015-10-05 board layout. check before manufacture
    [RPi_Hat.kicad_pcb]
2015-10-05 datasheet for push button switch
2015-10-05 changed LED resistor to 75ohms (0603 package)
    [RPi_GPIO.sch, RPi_Hat.kicad_pcb]
2015-10-06 checked vias and rerouted a 3.3V line. Ready for manufacture
    [RPi_Hat.kicad_pcb]
2015-10-06 gerbers for manufacture (rev.1 pcb)
    [RPi_Hat-B_Adhes.gbr, RPi_Hat-B_Cu.gbr, RPi_Hat-B_Mask.gbr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]
2015-10-06 included BoM for rev1
    [RF-Craft_BoM.csv]
2015-10-12 revised via sizes, as per board house recommendations
    [RPi_Hat.kicad_pcb]
2015-10-12 revised gerbers for b72ee2
    [RPi_Hat-B_Adhes.gbr, RPi_Hat-B_Cu.gbr, RPi_Hat-B_Mask.gbr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]
2015-10-12 deleted and regenerated gerbers to be sure
    [RPi_Hat-B_Adhes.gbr, RPi_Hat-B_Cu.gbr, RPi_Hat-B_Mask.gbr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]
2015-10-12 updated gitignore for kicad autosaves and gerber zips
2015-10-21 case draft
2015-10-26 added SPI to RFM69 lib
2015-10-27 changed serial responses to ACK/NAK/ERROR
    [receiver.ino, sketch.ino]
2015-10-27 added serial parsing and node id specification to button code
    but I had to comment out the sleep code for now
2015-10-29 panellised cut files for the case
2015-10-29 ignored output eps files in the case directory
2015-11-26 morse outgoing messages using the onboard LED
2016-03-18 Added RF-Craft.py, server.py and amended button-hello.py and button-test.py
2016-05-05 fixed 3.3v error, and button rotation bug
    [RPi_GPIO.sch, RPi_Hat.kicad_pcb, RPi_Hat.sch]
2016-05-06 gerbers and rev1.2 board text
    [RPi_Hat-B.Cu.gbr, RPi_Hat-B.Mask.gbr, RPi_Hat-B.Paste.gbr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]
2016-05-06 corrected the reduced solder mask on jumpers
    [RPi_Hat-B.Cu.gbr, RPi_Hat-B.Mask.gbr, RPi_Hat-B.Paste.gbr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]
2016-05-17 moved platformio structure to it's own folder and removed spi call in receiver
2016-05-17 changed arduino files to hardlinks (so arduino IDE doesn't follow)
    [button.ino, receiver.ino]
2016-06-09 Fixed default button to listen to to ID 1 and made clearer README.md background text
    [HelloPi.py]
2016-06-09 Added Arduino editing instructions for receivers and buttons
2016-07-01 solid logo, and 12mm kicad module of it
2016-07-05 moved Samtec footprint into project library
2016-07-05 resonator, analog input bank, source switch
    [RPi_GPIO.sch, RPi_Hat.sch]
2016-07-05 footprint and documentation for the 4PDT source selector switch
    [RPi_GPIO.sch]
2016-07-05 added node ID selection 4-way DIP switches
    [RPi_GPIO.sch]
2016-07-06 ISCP header and footprint assignments
    [RPi_GPIO.sch]
2016-07-06 fixed some old (out of date) footprint assignments
    [RPi_GPIO.sch]
2016-07-06 corrections to netlist
    [RPi_GPIO.sch]
2016-07-06 draft of rev.2 routed
    [RPi_Hat.kicad_pcb]
2016-07-06 board edited and ready for manual checks rev.2.rc1
    [RPi_Hat.kicad_pcb]
2016-07-06 changed FTDI to UART
    [RPi_Hat.kicad_pcb]
2016-07-07 upped the via pad anualar ring from 7.8thou to 11.8thou (+0.1mm)
    [RPi_Hat.kicad_pcb]
2016-07-07 moved to double sided rpi header footprint
    [RPi_Hat.kicad_pcb]
2016-07-07 gerbers for rev.2 board
    [RPi_Hat-B.Cu.gbr, RPi_Hat-B.Mask.gbr, RPi_Hat-B.Paste.gbr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]
2016-07-28 rev.2 solder mask svg for laser cutting
2016-07-29 added dip and slide switch check and combined gateway and button code
2016-08-01 reduced atmega soldermask area to 80% of original
2016-08-01 new blink sketch for the onboard led
2016-08-01 added startup blink for the onboard led
2016-08-02 Documentation of the Cooking and Assembly Process
2016-12-20 Added the necessary Arduino libraries to add to users Arduino Sketchbook
2016-12-21 Moved libraries to similar location as Shrimping.It so changing the arduino sketchbook to arduino will make it easier to find libraries in the sketches
2016-12-28 up to date with remote
    [RPi_GPIO.sch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]
2016-12-28 Revert "up to date with remote"
    This reverts commit 92056238b58dd1545c72053bc3b2b9ea0aa8e0b0.
    [RPi_GPIO.sch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]
2017-01-04 added missing schematic parts lib
2017-01-04 schematic and netlist changes for issues 1–5
    [RPi_GPIO.sch]
2017-01-04 rev3 board draft
    [RPi_Hat.kicad_pcb]
2017-01-04 draft BOM
    [1-click-bom.tsv]
2017-01-06 tweaked the text in the logo to avoid bleeding on the print
2017-01-12 new logo, and rev3 layout
    [RPi_Hat-B.Cu.gbr, RPi_Hat-B.Mask.gbr, RPi_Hat-B.Paste.gbr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]
2017-03-08 Fixed spacing and code inserts in APIRef for Joseph
2021-06-03 fixed BoM mission colomn
    [RF-Craft_BoM.csv]
